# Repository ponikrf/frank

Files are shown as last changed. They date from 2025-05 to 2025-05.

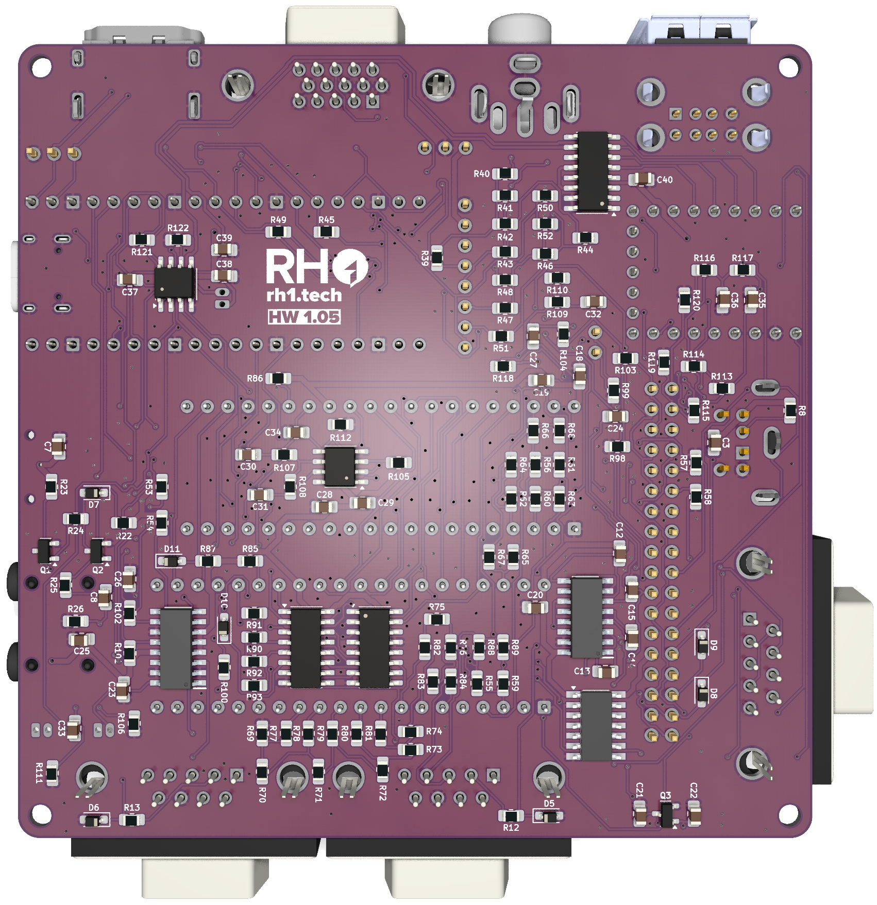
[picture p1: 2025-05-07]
hardware/turbofrank/DOCS/back.png

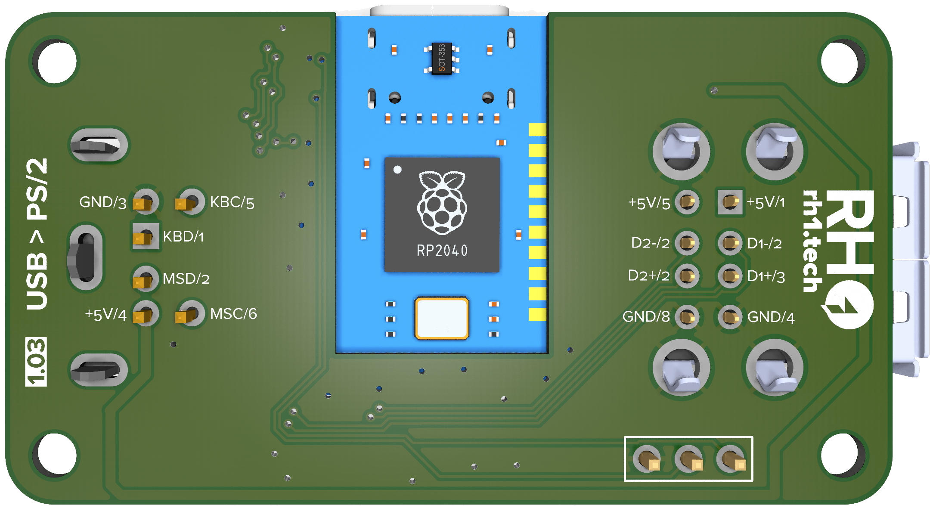
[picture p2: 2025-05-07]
hardware/usb2ps2/DOCS/back.png

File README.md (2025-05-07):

# FRANK

FRANK is a versatile hardware emulation platform based on Raspberry Pico and Raspberry Zero. It is a hardware fork of the [Murmulator](https://murmulator.ru/) project by [Alex Ekb](https://t.me/Alex_Eburg), incorporating numerous additional features.

The name "FRANK" is derived from "Frankenstein" as it integrates various components from different projects, similar to how Dr. Frankenstein created his monster from different parts. This combination enables FRANK to offer a unique and powerful set of capabilities.

## Supported Platforms

FRANK supports emulation for a variety of platforms, including:

* ZX Spectrum (48K, 128K and other models, including clones)
* IBM PC XT 8088
* BK-0011М (soviet 8 bit home computer)
* Radio 86RK (soviet 8 bit home computer)
* Atari 800
* NES/Famicom (also known as Dendy)
* Sega Master System
* Sega Game Gear
* NEC PC Engine / TurboGrafx 16
* Sega MegaDrive / Genesis
* Nintendo GameBoy
* Nintendo GameBoy Color
* Watara Supervision
* Atari Lynx
* Bandai Wonderswan
* NeoGeo Pocket Color
* Picomite MMBasic
* VersaTerm
* DOOM
* Macintosh 512K
* MurmulatorOS

## FRANK Models

Currently there are the following versions of FRANK available:

* [FRANK M1](./hardware/frank_m1) (latest hardware revision: 1.17)
* [FRANK M2](./hardware/frank_m2) (latest hardware revision: 1.03)
* [MiniFRANK RM1](./hardware/minifrank_rm1) (latest hardware revision: 2.07)
* [TurboFRANK](./hardware/turbofrank) (latest hardware revision: 1.07)

## Side Projects

* [HDMI2VGA](./hardware/hdmi2vga) - HDMI to VGA/Soft Composite passive adaptor (latest hardware revision: 2.03)
* [USB2PS2](./hardware/usb2ps2) - USB to PS/2 adapter built on RP2040-Zero (latest hardware revision: 1.03)

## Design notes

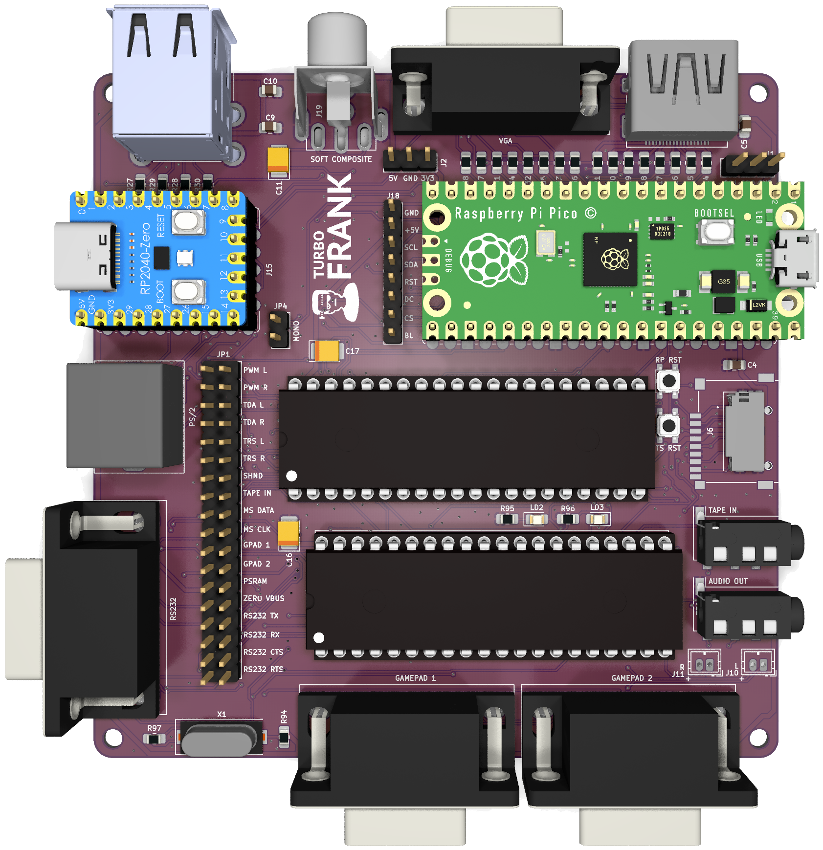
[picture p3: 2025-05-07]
hardware/turbofrank/DOCS/front.png

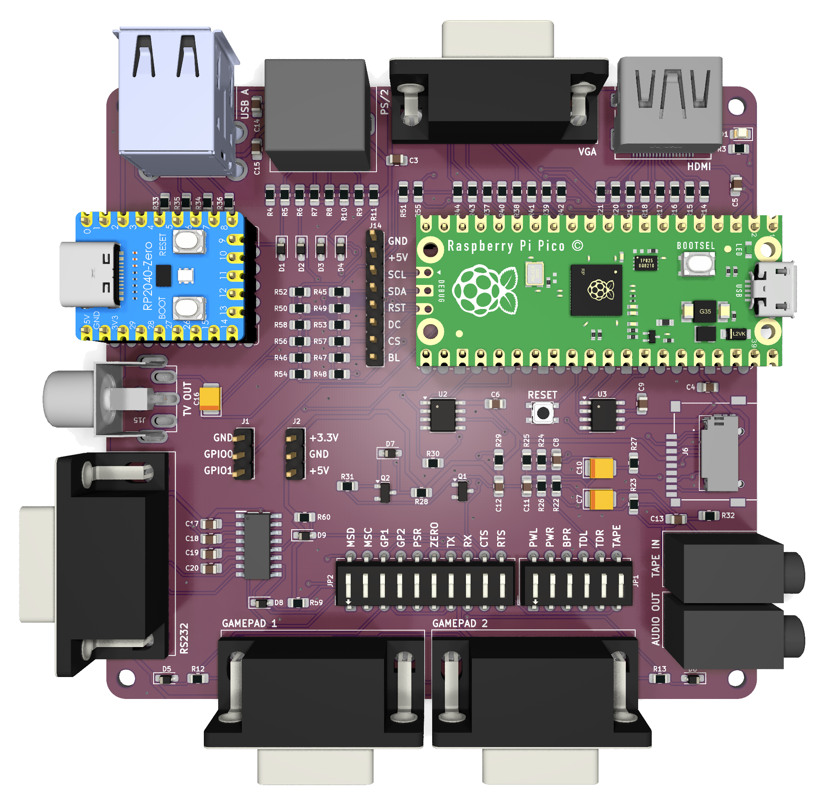
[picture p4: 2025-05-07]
hardware/frank_m1/DOCS/front.png

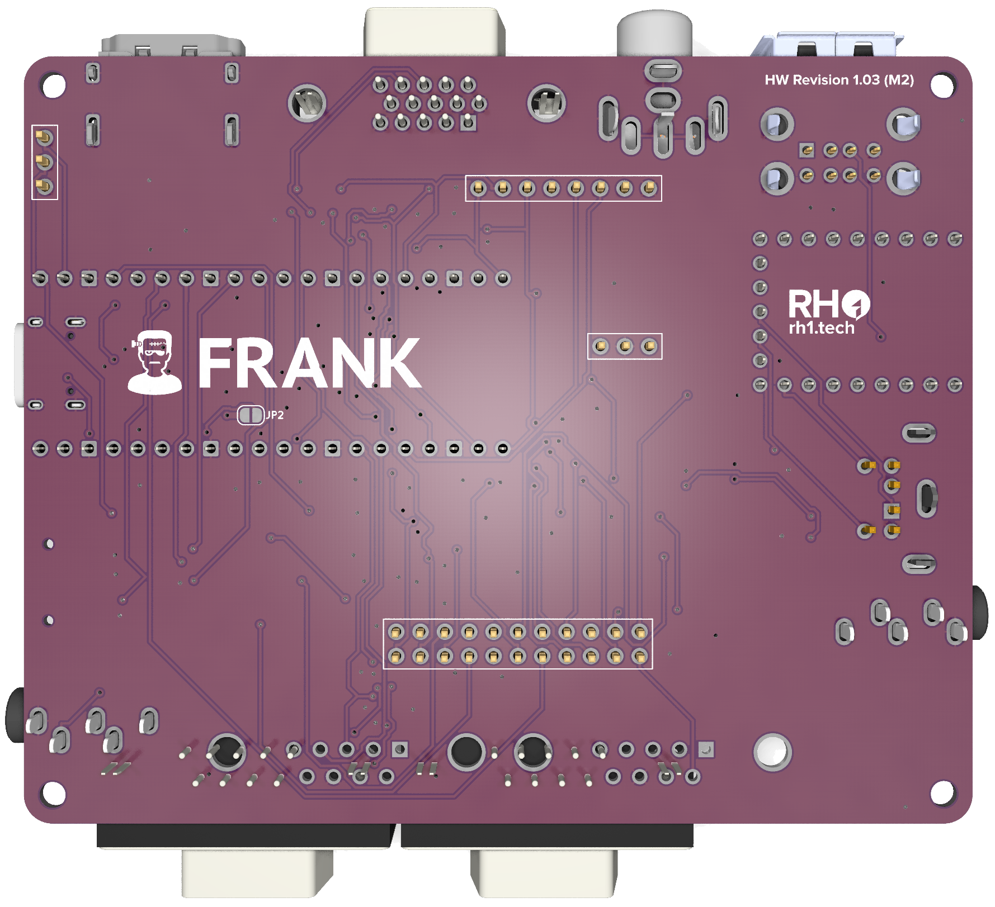
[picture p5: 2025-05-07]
hardware/frank_m2/DOCS/back.png

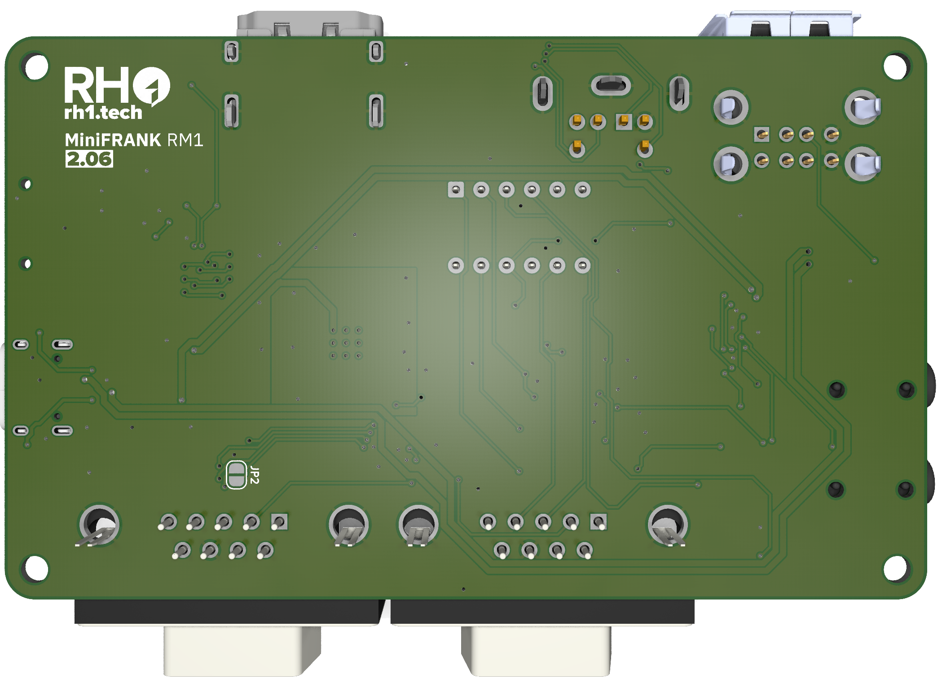
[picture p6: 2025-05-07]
hardware/minifrank_rm1/DOCS/back.png

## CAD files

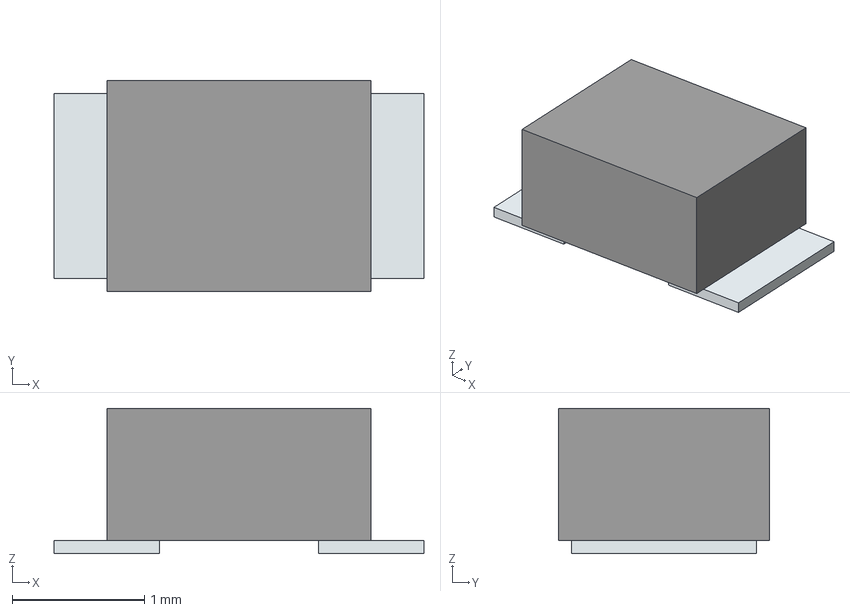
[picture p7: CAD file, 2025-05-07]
lab/minifrank_rm2/3D/ASMPH-0806-3R3M-T.stp
2.80 x 1.60 x 1.10 mm
Pins

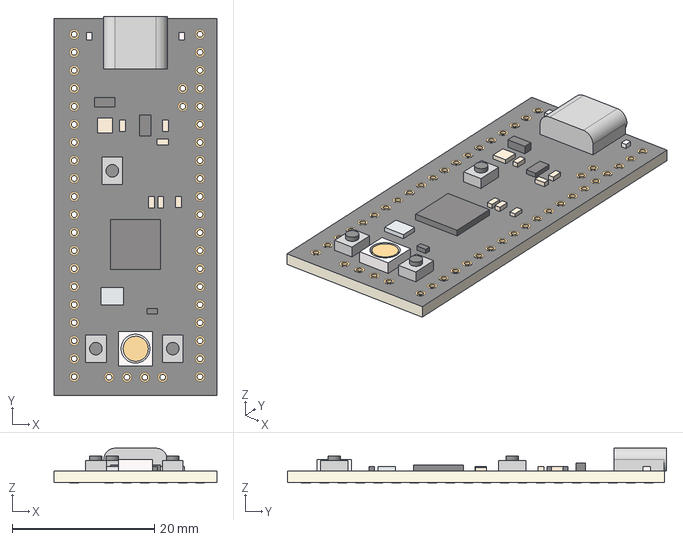
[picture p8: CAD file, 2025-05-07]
hardware/frank_m1/3D/PICO Black.step
22.9 x 53.3 x 4.88 mm

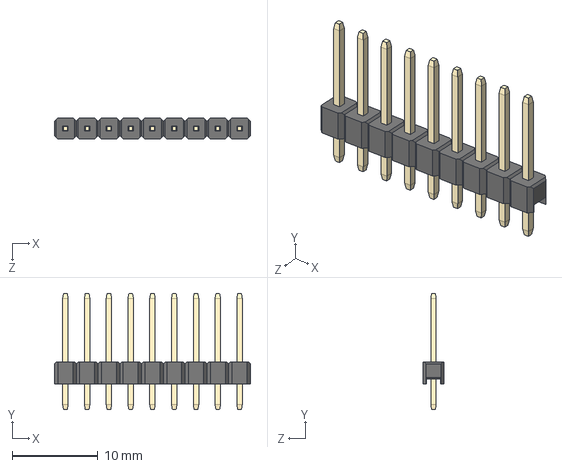
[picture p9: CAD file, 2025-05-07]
hardware/frank_m2/3D/1x9 Male Pin Header.STEP
22.9 x 13.5 x 2.50 mm

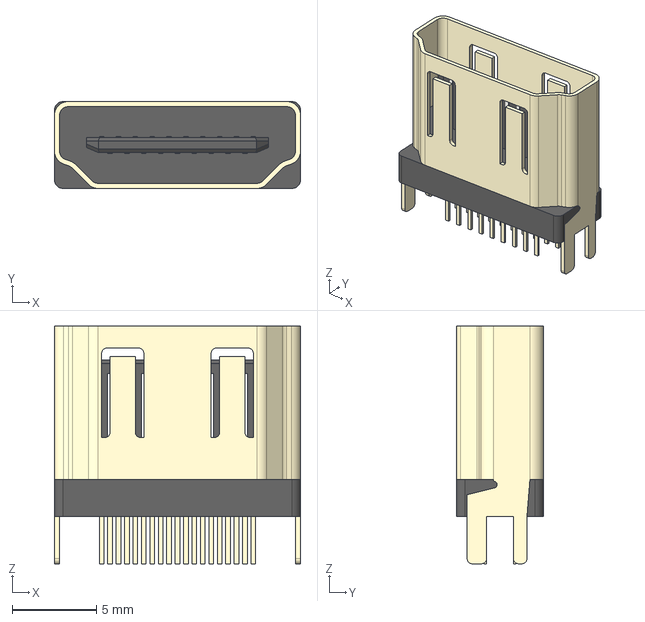
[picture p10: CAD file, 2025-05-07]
hardware/hdmi2vga/3D/HDMI_vertical.stp
14.6 x 5.15 x 14.1 mm

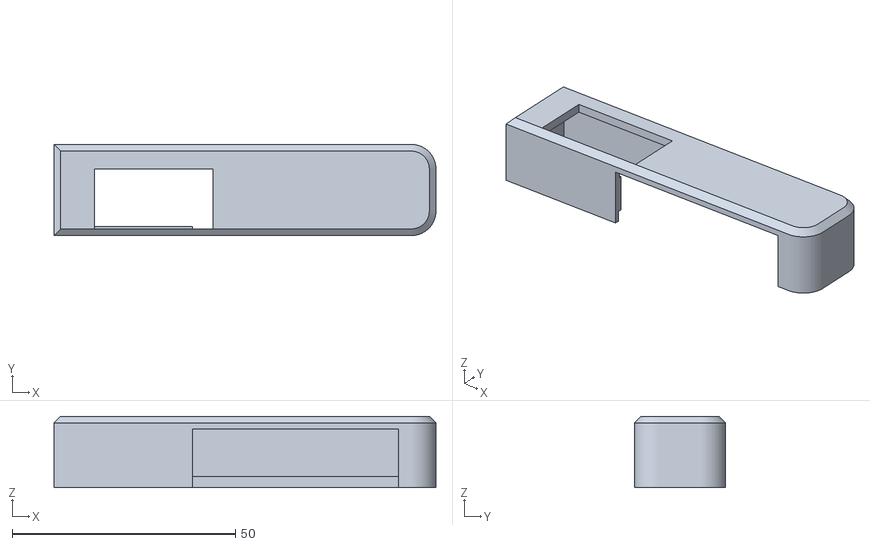
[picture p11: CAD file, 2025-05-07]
hardware/hdmi2vga/CASE/2_02/top.stl
85.5 x 20.4 x 16.0

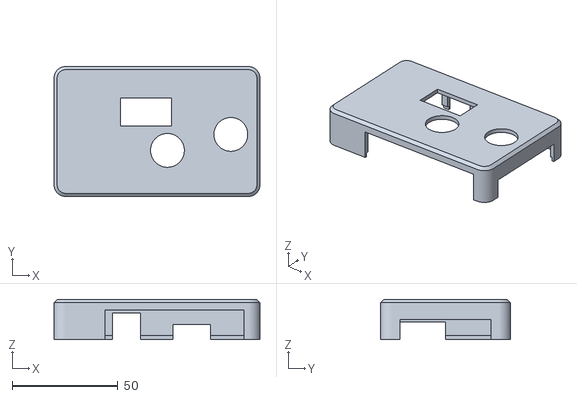
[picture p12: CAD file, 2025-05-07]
hardware/minifrank_rm1/CASE/2_06/top.stl
97.5 x 61.5 x 19.0

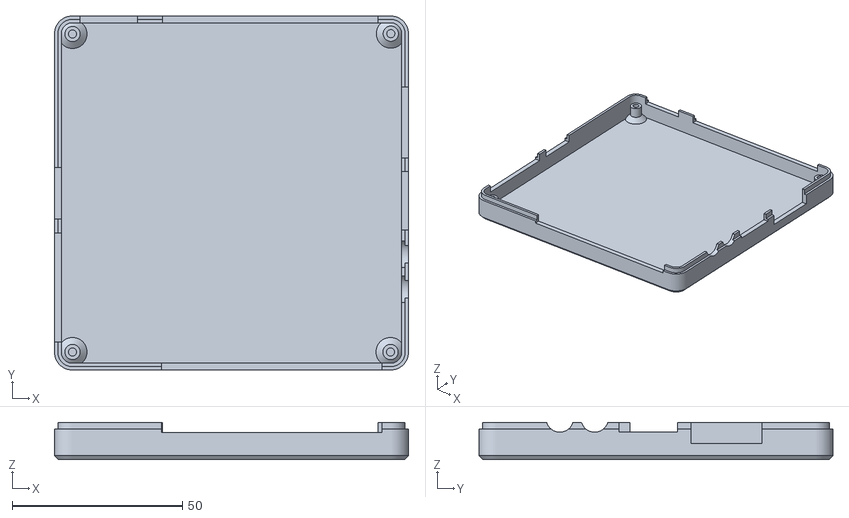
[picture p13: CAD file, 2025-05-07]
hardware/turbofrank/CASE/1_06/bottom.stl
104.0 x 104.0 x 11.0

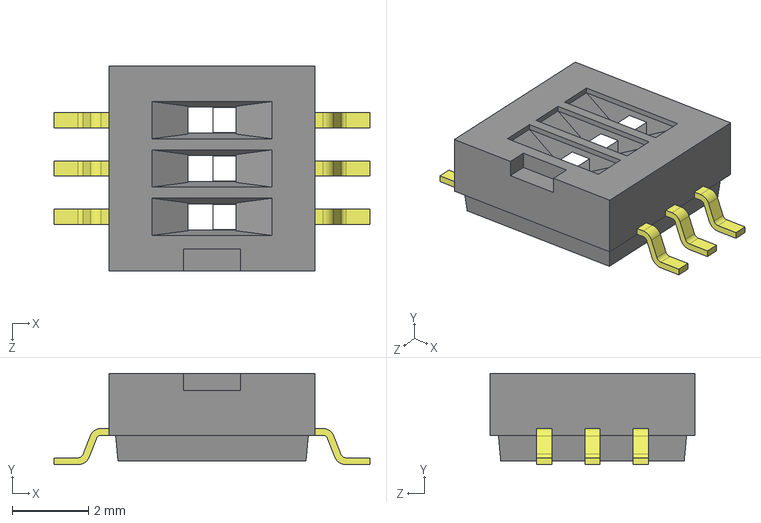
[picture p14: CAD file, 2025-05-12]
lab/minifrank_rm2/3D/DS05-127-2-03BK-SMT-TR.step
8.30 x 2.40 x 5.38 mm

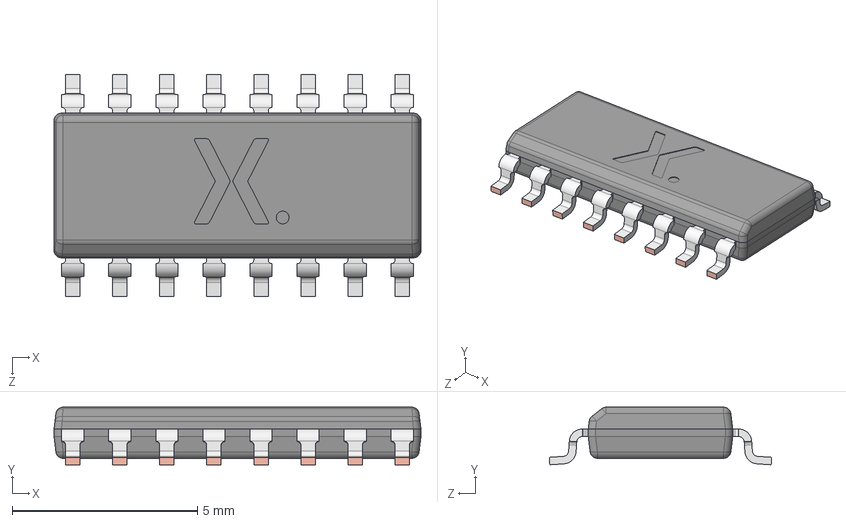
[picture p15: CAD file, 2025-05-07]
lab/nyx2/3D/74HC4052D,653.stp
9.90 x 1.56 x 6.00 mm
SOT109-1 lower body
SOT109-1 upper body
SOT109-1 Lead

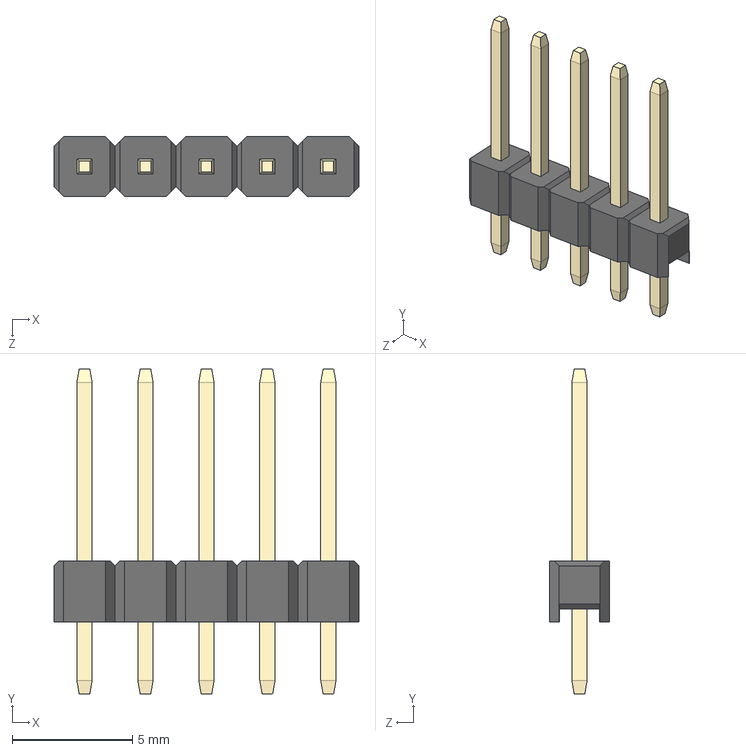
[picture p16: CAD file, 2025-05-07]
hardware/frank_m1/3D/1x5 Male Pin Header.STEP
12.7 x 13.5 x 2.50 mm

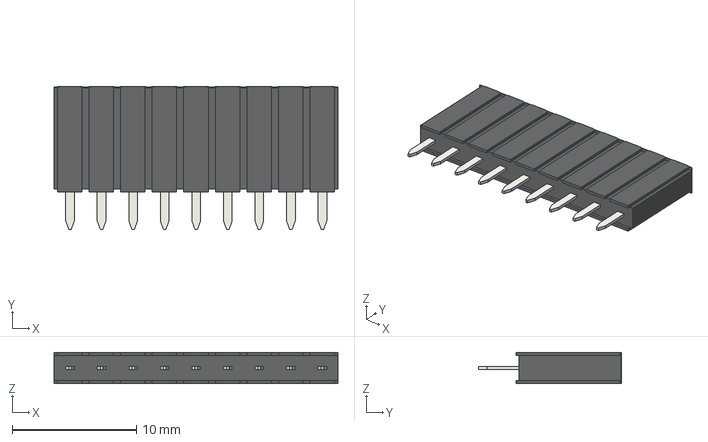
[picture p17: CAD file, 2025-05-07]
hardware/frank_m2/3D/FHU-1x9.step
22.9 x 11.5 x 2.50 mm

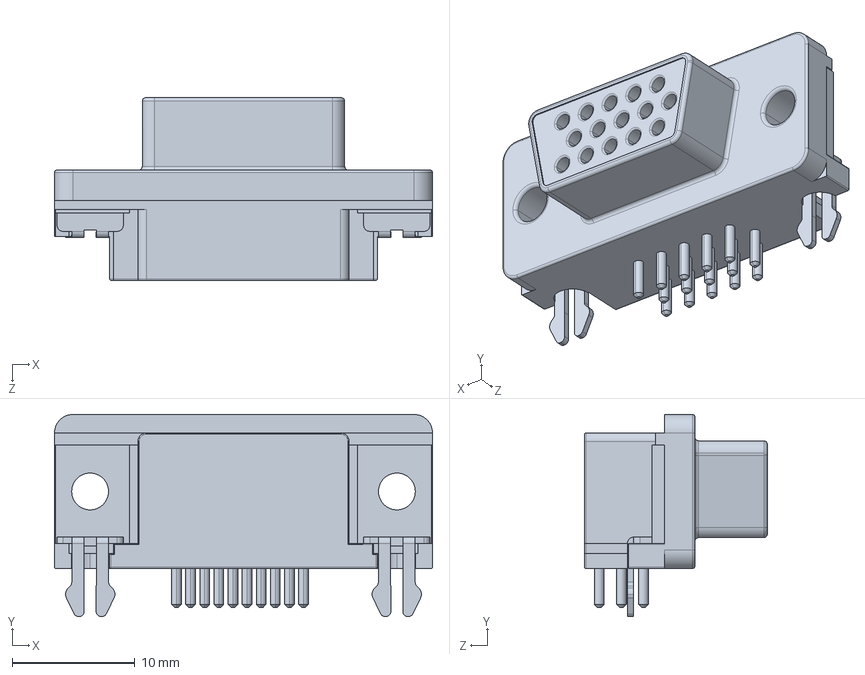
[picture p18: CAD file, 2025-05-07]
hardware/hdmi2vga/3D/VGA connector on plate (short).STEP
30.8 x 16.5 x 14.9 mm

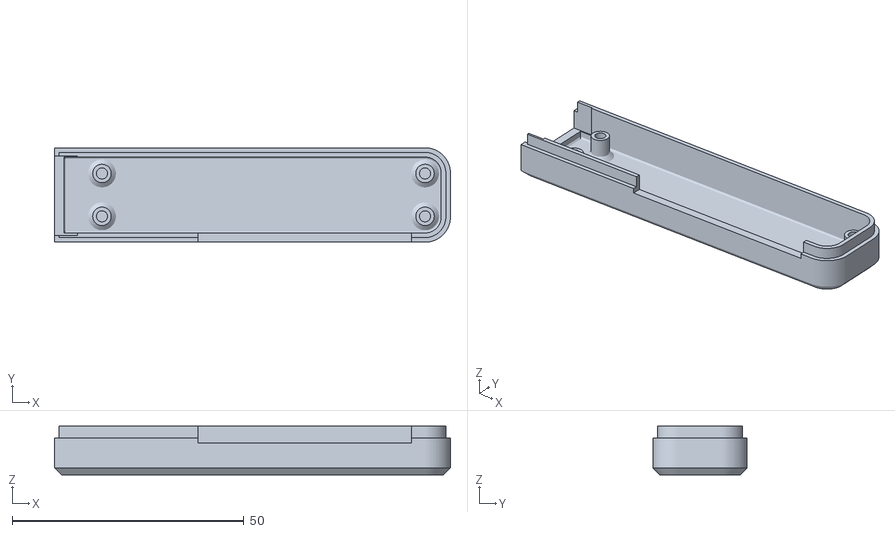
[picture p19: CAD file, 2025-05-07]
hardware/hdmi2vga/CASE/2_02/bottom.stl
85.5 x 20.4 x 10.5

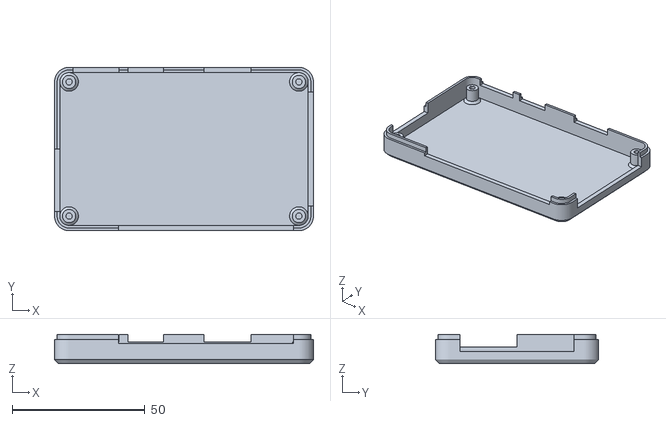
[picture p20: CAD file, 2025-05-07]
hardware/minifrank_rm1/CASE/2_06/bottom.stl
97.5 x 61.5 x 11.0

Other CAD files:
hardware/turbofrank/CASE/1_06/top.stl
lab/minifrank_rm2/3D/TS3USB221RSER.stp
hardware/frank_m1/3D/1x20 Male Pin Header.STEP
hardware/frank_m1/3D/FHU-1x20.step
hardware/frank_m1/3D/FHU-1x5.step
hardware/frank_m2/3D/1x20 Male Pin Header.STEP
hardware/frank_m2/3D/FHU-1x20.step
hardware/frank_m2/3D/FHU-1x5.step
hardware/turbofrank/3D/1x20 Male Pin Header.STEP
hardware/turbofrank/3D/FHU-1x20.step
hardware/turbofrank/3D/FHU-1x5.step
hardware/turbofrank/3D/Micro_SD_Card_and_Holder.stp
lab/minifrank_rm2/3D/3225 SMD Crystal Oscillator.STEP
lab/minifrank_rm2/3D/47571-0001.stp
lab/minifrank_rm2/3D/CUI_DEVICES_RCJ-013.step
lab/minifrank_rm2/3D/DS05-127-2-04BK-SMT-TR.step
lab/minifrank_rm2/3D/DSUB-15-HD_Male_Horizontal_P2.29x1.98mm_EdgePinOffset3.03mm_Housed_MountingHolesOffset4.94mm.step
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

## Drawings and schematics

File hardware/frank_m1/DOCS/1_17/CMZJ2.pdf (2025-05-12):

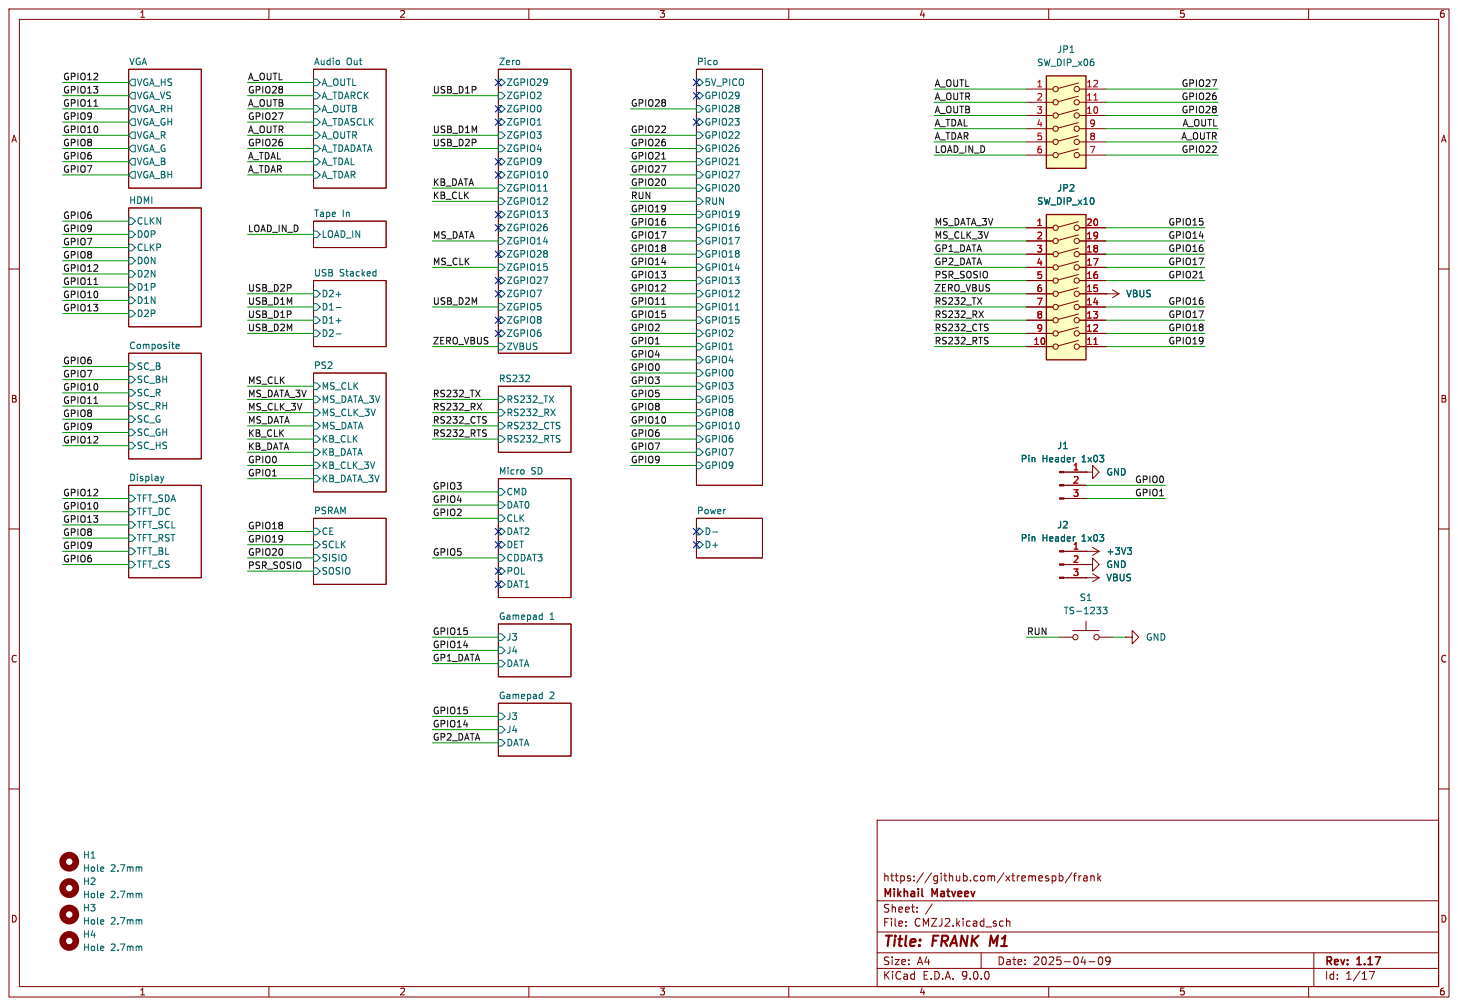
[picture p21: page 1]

J1 Pin Header 1x03 GND GND 123

DAT0 CLK DAT2 DET CDDAT3 POL DAT1 Micro SD

https://github.com/xtremespb/frank

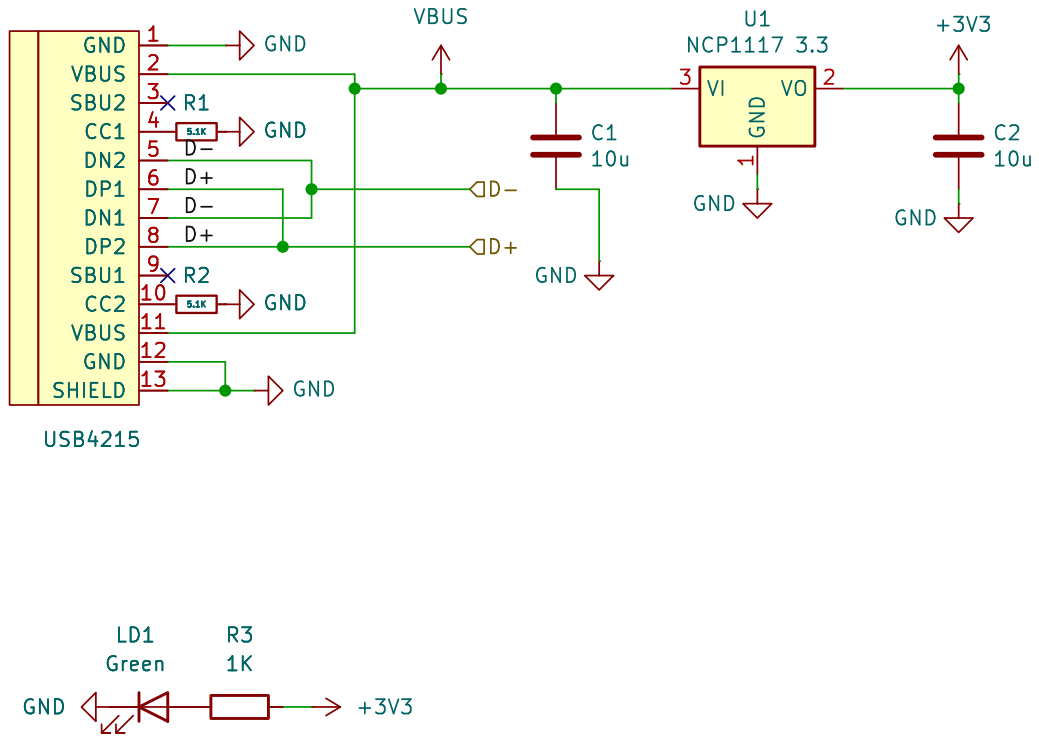
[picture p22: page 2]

https://github.com/xtremespb/frank R2

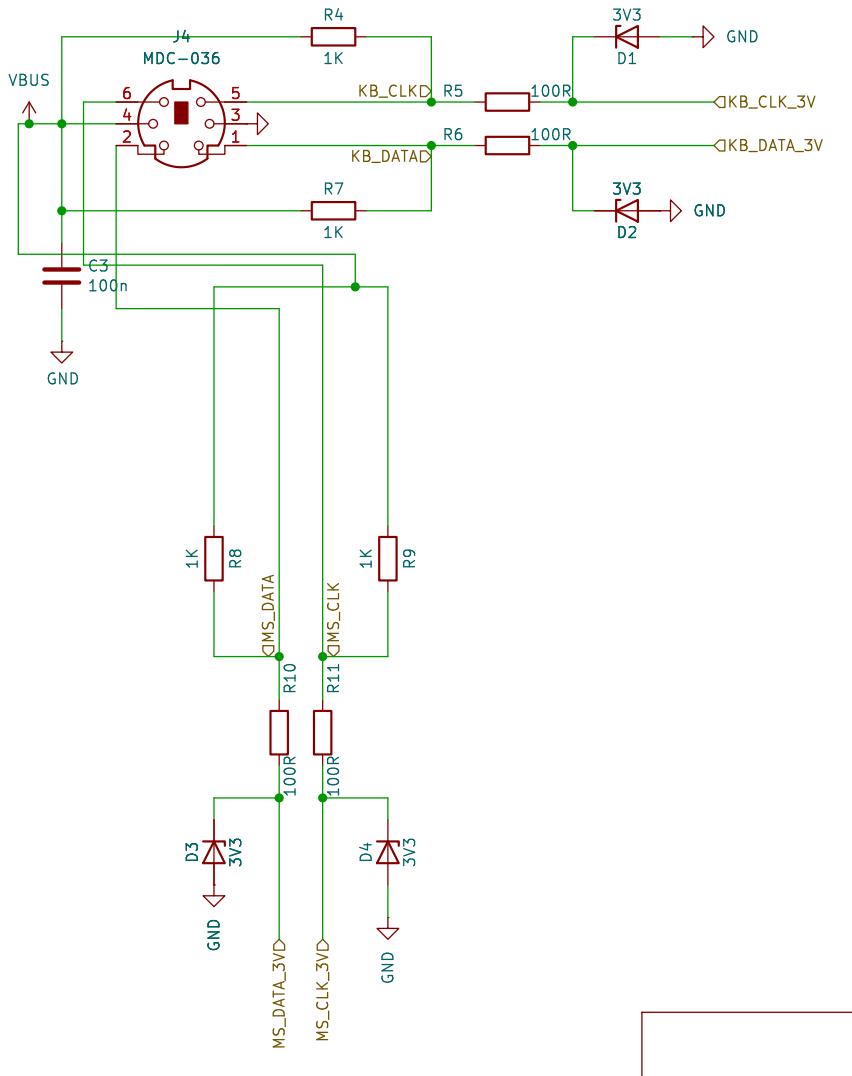
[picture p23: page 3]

https://github.com/xtremespb/frank

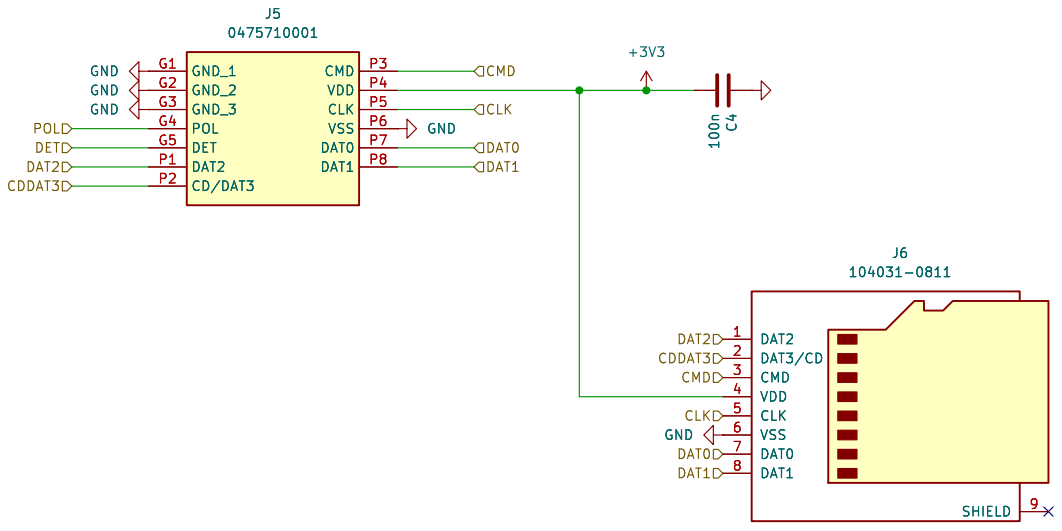
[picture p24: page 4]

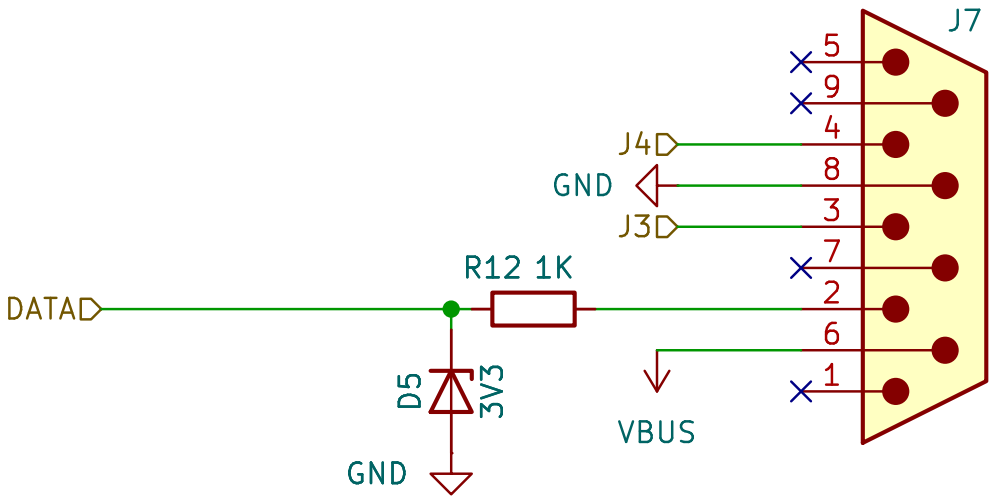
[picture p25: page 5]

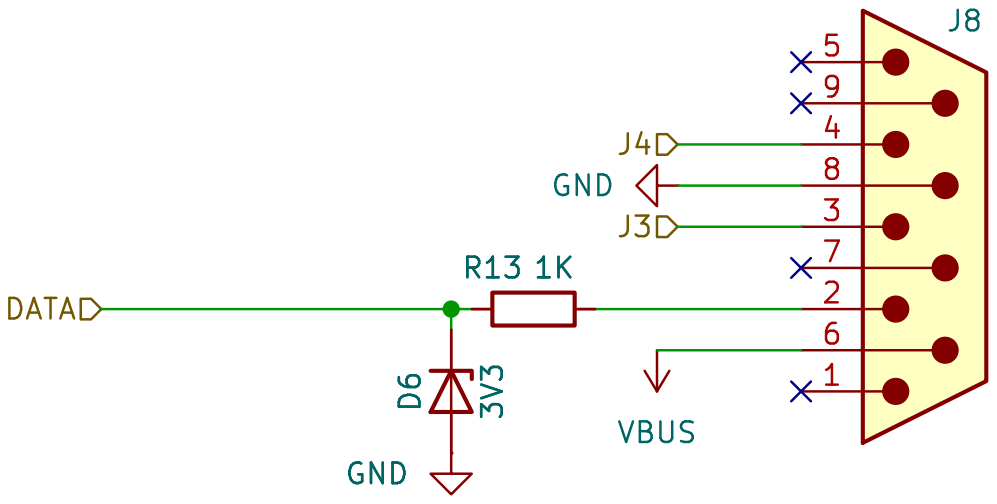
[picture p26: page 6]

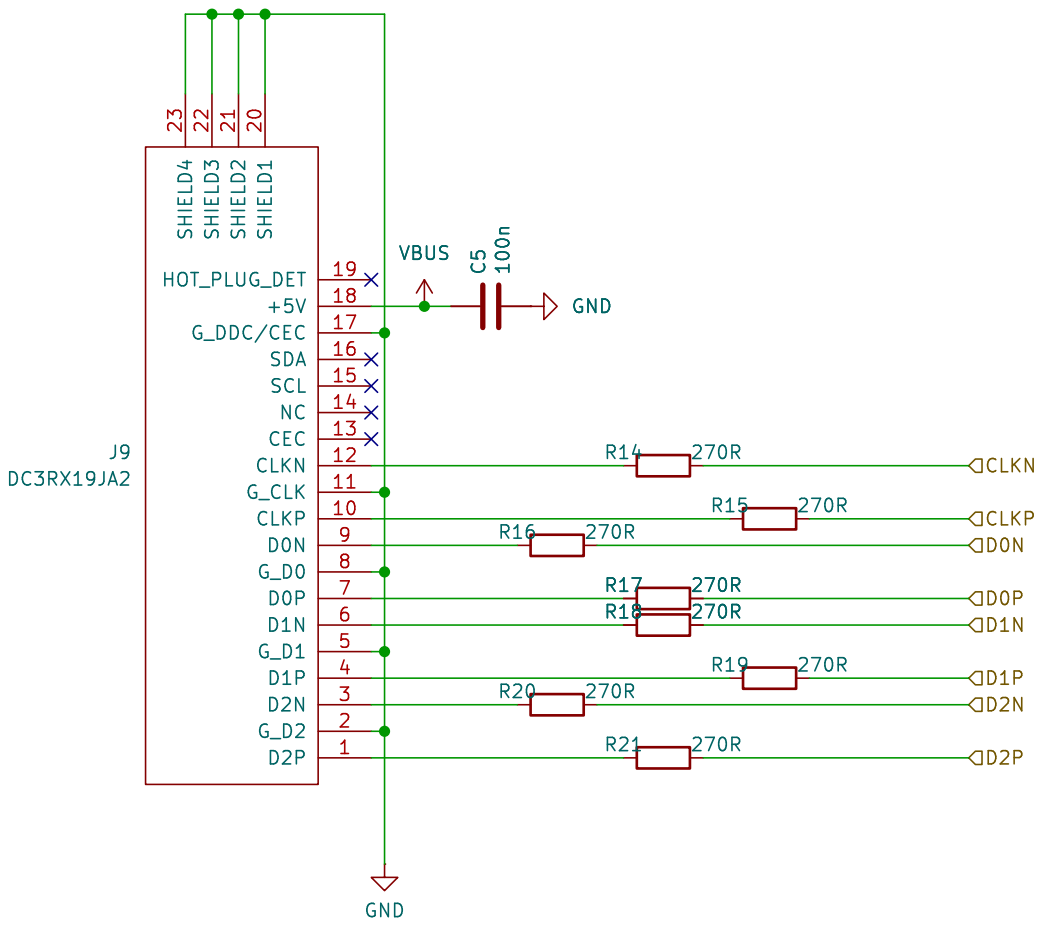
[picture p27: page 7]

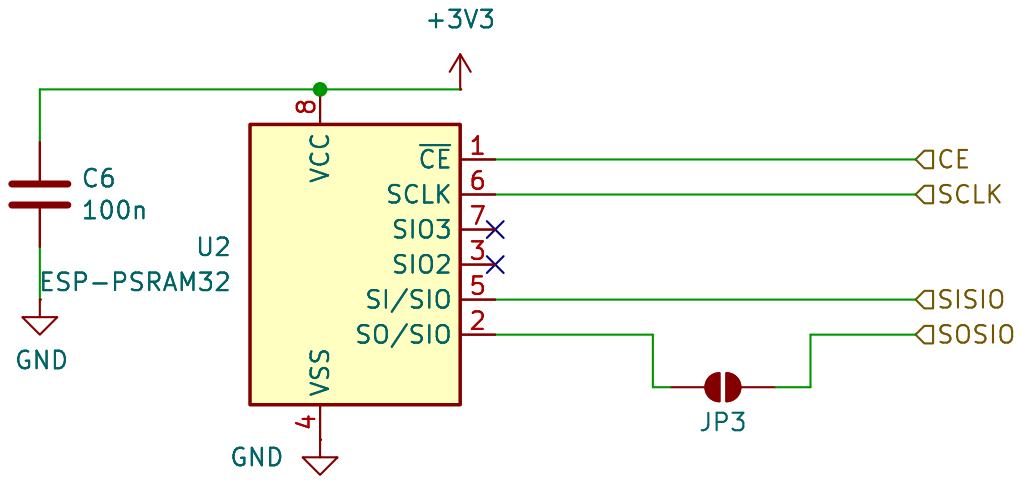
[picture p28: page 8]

4 ~{CE}1 SCLK 6 SIO3 7 SIO2 3 SI/SIO 5 SO/SIO 2 +3V3

4 ~{CE}1 SCLK 6 SIO3 7 SIO2 3 SI/SIO 5 SO/SIO 2 U2 ESP-PSRAM32 GND

https://github.com/xtremespb/frank C6

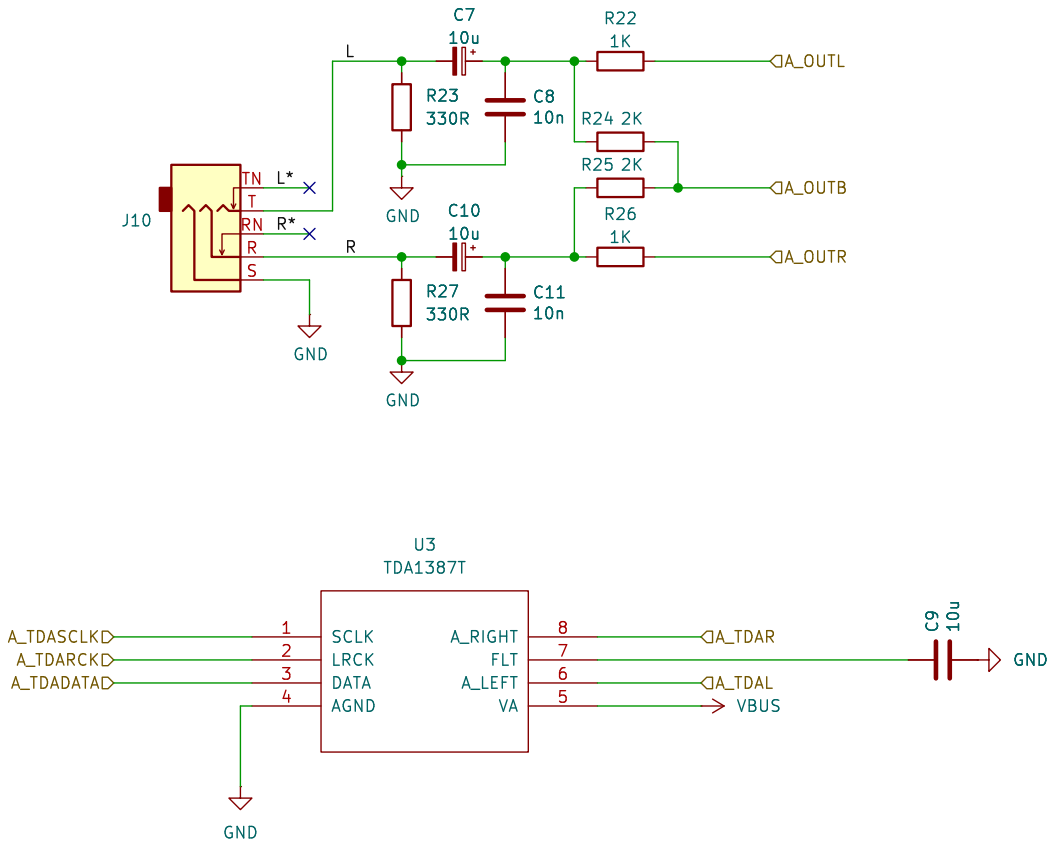
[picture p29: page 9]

https://github.com/xtremespb/frank

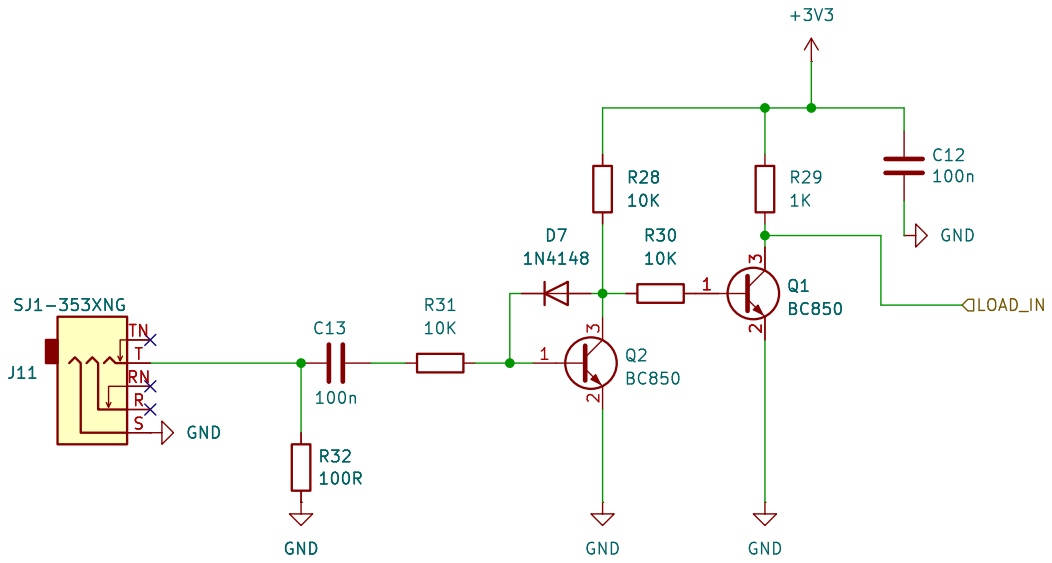
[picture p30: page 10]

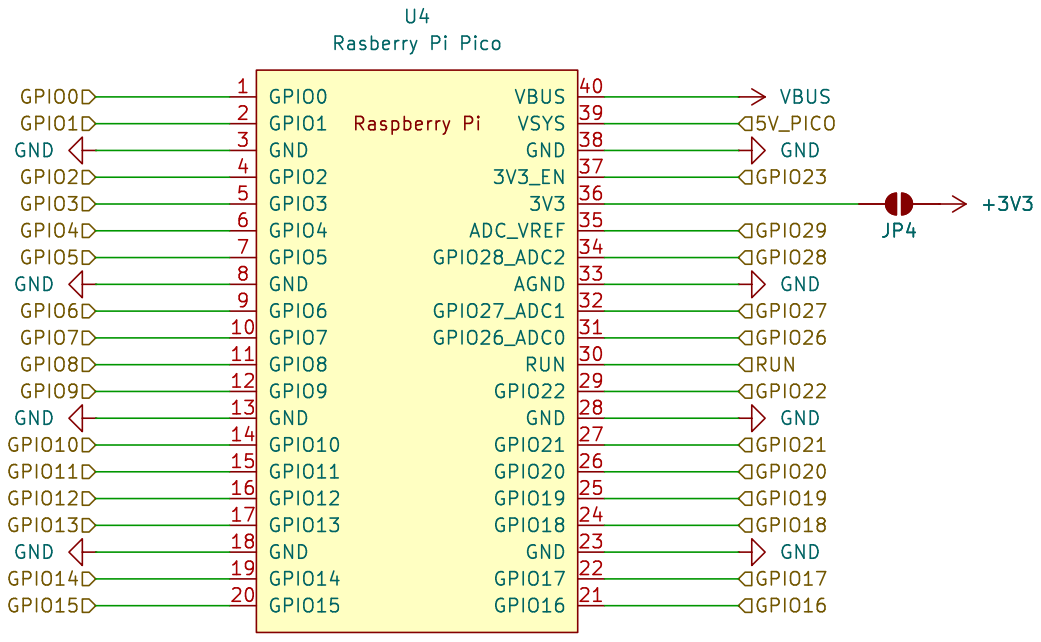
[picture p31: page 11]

https://github.com/xtremespb/frank GND

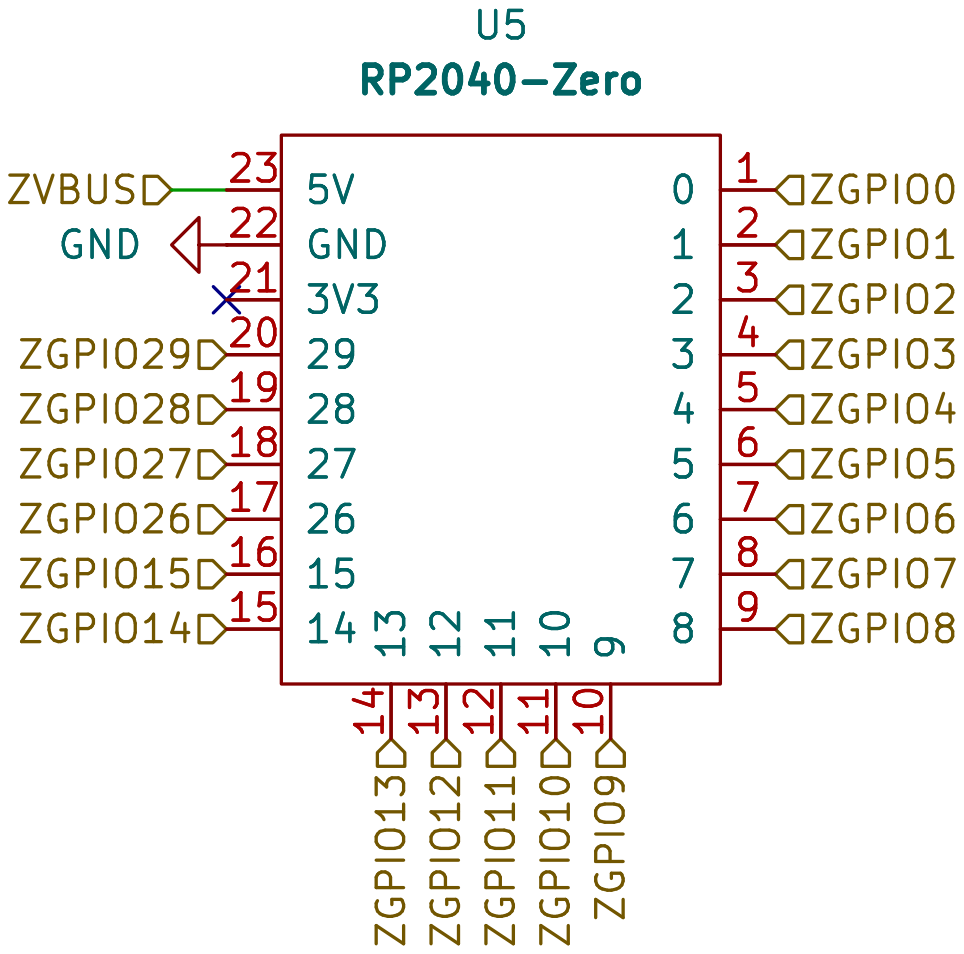
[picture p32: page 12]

https://github.com/xtremespb/frank GND



https://github.com/xtremespb/frank


https://github.com/xtremespb/frank


https://github.com/xtremespb/frank


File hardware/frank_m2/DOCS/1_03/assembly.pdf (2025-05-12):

# D3 R46 J15


https://github.com/xtremespb/frank Black And White TOP - Page 1/4

File: HR3FQ.kicad_pcb Sheet: Black And White TOP Mikhail Matveev

D Date: 2025-03-16 KiCad; E.D.A. 9.0.0 Size: A4; Rev: 1.03; File: HR3FQ.kicad_pcb Sheet: Black; And; White; BOT Mikhail; Matveev; https://github.com/xtremespb/frank Black; BOT -; Page 2/4

Id: /1 Title: FRANK M2

# D3 R46 J15


D Date: 2025-03-16 KiCad; E.D.A. 9.0.0 Size: A4; Rev: 1.03; File: HR3FQ.kicad_pcb Sheet: Colored; BOT Mikhail; Matveev; https://github.com/xtremespb/frank Colored; BOT -; Page 4/4; Jumper (Solder)

Id: /1 Title: FRANK M2

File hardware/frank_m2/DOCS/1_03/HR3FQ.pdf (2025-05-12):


ZERO_VBUS
DAT0 CLK DAT2 DET CDDAT3 POL DAT1 Micro SD

https://github.com/xtremespb/frank


1 VO 2 U1 GND NCP1117 3.3 1 VBUS 2 SBU2 3 CC1 4 DN2 5 DP1 6 DN1 7 DP2 8 SBU1 9 CC2 10 VBUS 11 GND 12 SHIELD 13 USB4215 GND

https://github.com/xtremespb/frank


https://github.com/xtremespb/frank GND



https://github.com/xtremespb/frank


https://github.com/xtremespb/frank



https://github.com/xtremespb/frank


https://github.com/xtremespb/frank SR
100R GND


https://github.com/xtremespb/frank


https://github.com/xtremespb/frank



https://github.com/xtremespb/frank



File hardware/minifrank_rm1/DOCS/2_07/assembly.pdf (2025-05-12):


MM USB AUDIO RESET BOOT AUDIO OUT TAPE IN R1 U1 C8 R49 R46 R8 R11 R57 U2 C33 C11 C39 C34 D3 R50 R27D4 C20 C31

https://github.com/xtremespb/frank Black And White TOP - Page 1/4

File: minifrank_rm1.kicad_pcb Sheet: Black And White TOP Mikhail Matveev

D Date: 2025-04-24 KiCad; E.D.A. 9.0.0 Size: A4; Rev: 2.07; File: minifrank_rm1.kicad_pcb Sheet: Black; And; White; BOT Mikhail; Matveev; https://github.com/xtremespb/frank Black; BOT -; Page 2/4

Id: /1 Title: MiniFRANK RM1


D Date: 2025-04-24 KiCad; E.D.A. 9.0.0 Size: A4; Rev: 2.07; File: minifrank_rm1.kicad_pcb Sheet: Colored; BOT Mikhail; Matveev; https://github.com/xtremespb/frank Colored; BOT -; Page 4/4 Jumper (Solder)

Id: /1 Title: MiniFRANK RM1

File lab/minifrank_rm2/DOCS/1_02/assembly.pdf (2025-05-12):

J8 | R6U1 R10 | R47 R³¹ | JP¹ R11 | C⁴⁰ R⁴⁰ R8 C13 | R7 1 | 2 | 3 | 4 | 5 | 6 1 | 2 | 3 | 4 | 5 | 6 ABCD | ABCD Date: 2025-05-11 KiCad E.D.A. 9.0.0 Size: A4 | Rev: 1.02


BOOT USB TAPE IN GAMEPAD 1 TAPE IN AUDIO OUT AUDIO

https://github.com/xtremespb/frank Black And White TOP - Page 1/4

File: minifrank_rm2.kicad_pcb Sheet: Black And White TOP Mikhail Matveev

1 | 2 | 3 | 4 | 5 | 6

A

D Date: 2025-05-11 KiCad; E.D.A. 9.0.0 Size: A4; Rev: 1.02; File: minifrank_rm2.kicad_pcb Sheet: Black; And; White; BOT Mikhail; Matveev; https://github.com/xtremespb/frank Black; BOT -; Page 2/4

Id: /1 Title: MiniFRANK RM2

1 | 2 | 3 | 4 | 5 | 6 1 | 2 | 3 | 4 | 5 | 6 ABCD | ABCD Date: 2025-05-11 KiCad | E.D.A. 9.0.0 Size: A4 | Rev: 1.02
https://github.com/xtremespb/frank Colored | TOP - | Page 3/4 | BOOT USB TAPE IN GAMEPAD ¹ | TAPE IN AUDIO OUT | AUDIO


1 | 2 | 3 | 4 | 5 | 6

A

D Date: 2025-05-11 KiCad; E.D.A. 9.0.0 Size: A4; Rev: 1.02; File: minifrank_rm2.kicad_pcb Sheet: Colored; BOT Mikhail; Matveev; https://github.com/xtremespb/frank Colored; BOT -; Page 4/4

Id: /1 Title: MiniFRANK RM2

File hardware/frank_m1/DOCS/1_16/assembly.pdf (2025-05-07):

J1 | R49 | R⁵¹ | C⁸ R52 U⁶ | R⁴² | R¹⁹ 1 | 2 | 3 | 4 | 5 | 6 1 | 2 | 3 | 4 | 5 | 6 ABCD | ABCD Date: 2025-03-26 KiCad E.D.A. 9.0.0 Size: A4 | Rev: 1.16

R3 100R


https://github.com/xtremespb/frank Black And White TOP - Page 1/4

File: CMZJ2.kicad_pcb Sheet: Black And White TOP Mikhail Matveev

1 | 2 | 3 | 4 | 5 | 6

A

D Date: 2025-03-26 KiCad; E.D.A. 9.0.0 Size: A4; Rev: 1.16; File: CMZJ2.kicad_pcb Sheet: Black; And; White; BOT Mikhail; Matveev; https://github.com/xtremespb/frank Black; BOT -; Page 2/4; Jumper; (Solder)

Id: /1 Title: FRANK M1

1 | 2 | 3 | 4 | 5 | 6

A

D Date: 2025-03-26 KiCad; E.D.A. 9.0.0 Size: A4; Rev: 1.16; File: CMZJ2.kicad_pcb Sheet: Colored; BOT Mikhail; Matveev; https://github.com/xtremespb/frank Colored; BOT -; Page 3/4; Jumper; (Solder)

Id: /1 Title: FRANK M1

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

R3 100R


https://github.com/xtremespb/frank Colored TOP - Page 4/4

File: CMZJ2.kicad_pcb Sheet: Colored TOP Mikhail Matveev

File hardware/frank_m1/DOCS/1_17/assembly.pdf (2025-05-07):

# VGA RTS TDR


https://github.com/xtremespb/frank Black And White TOP - Page 1/4

File: CMZJ2.kicad_pcb Sheet: Black And White TOP Mikhail Matveev

D Date: 2025-04-09 KiCad; E.D.A. 9.0.0 Size: A4; Rev: 1.17; File: CMZJ2.kicad_pcb Sheet: Black; And; White; BOT Mikhail; Matveev; https://github.com/xtremespb/frank Black; BOT -; Page 2/4

Id: /1 Title: FRANK M1

# VGA RTS TDR


D Date: 2025-04-09 KiCad; E.D.A. 9.0.0 Size: A4; Rev: 1.17; File: CMZJ2.kicad_pcb Sheet: Colored; BOT Mikhail; Matveev; https://github.com/xtremespb/frank Colored; BOT -; Page 4/4; Jumper; (Solder)

Id: /1 Title: FRANK M1

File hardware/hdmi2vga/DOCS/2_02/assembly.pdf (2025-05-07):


D Date: 2025-03-04 KiCad; E.D.A. 9.0.0 Size: A4; Rev: 2.01; Id: /1 Title: HDMI to VGA Passive Adapter File: hdmi2vgaP.kicad_pcb Sheet: Black; And; White; BOT Mikhail; Matveev; https://github.com/xtremespb/frank Black; BOT -; Page 2/2

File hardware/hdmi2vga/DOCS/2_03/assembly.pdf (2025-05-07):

D Date: 2025-05-07 KiCad; E.D.A. 9.0.0 Size: A4; Rev: 2.03; Id: /1 Title: HDMI2VGA; File: hdmi2vga.kicad_pcb Sheet: Black; And; White; TOP Mikhail; Matveev; https://github.com/xtremespb/frank Black; TOP -; Page

D Date: 2025-05-07 KiCad; E.D.A. 9.0.0 Size: A4; Rev: 2.03; Id: /1 Title: HDMI2VGA; File: hdmi2vga.kicad_pcb Sheet: Black; And; White; BOT Mikhail; Matveev; https://github.com/xtremespb/frank Black; BOT -; Page 2/4

D Date: 2025-05-07 KiCad; E.D.A. 9.0.0 Size: A4; Rev: 2.03; Id: /1 Title: HDMI2VGA; File: hdmi2vga.kicad_pcb Sheet: Colored; TOP Mikhail; Matveev; https://github.com/xtremespb/frank Colored; TOP -; Page 3/4 L1

D Date: 2025-05-07 KiCad; E.D.A. 9.0.0 Size: A4; Rev: 2.03; Id: /1 Title: HDMI2VGA; File: hdmi2vga.kicad_pcb Sheet: Colored; BOT Mikhail; Matveev; https://github.com/xtremespb/frank Colored; BOT -; Page 4/4

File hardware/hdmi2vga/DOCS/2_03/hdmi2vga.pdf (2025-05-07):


https://github.com/xtremespb/frank GND

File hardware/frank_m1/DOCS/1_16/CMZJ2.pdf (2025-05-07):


DAT0 CLK DAT2 DET CDDAT3 POL DAT1 Micro SD


https://github.com/xtremespb/frank



https://github.com/xtremespb/frank


https://github.com/xtremespb/frank


https://github.com/xtremespb/frank


https://github.com/xtremespb/frank


4 ~{CE}1 SCLK 6 SIO3 7 SIO2 3 SI/SIO 5 SO/SIO 2 U2 ESP-PSRAM32 C6

4 ~{CE}1 SCLK 6 SIO3 7 SIO2 3 SI/SIO 5 SO/SIO 2 C6

https://github.com/xtremespb/frank


https://github.com/xtremespb/frank


https://github.com/xtremespb/frank


https://github.com/xtremespb/frank


https://github.com/xtremespb/frank


https://github.com/xtremespb/frank


https://github.com/xtremespb/frank


https://github.com/xtremespb/frank


https://github.com/xtremespb/frank


J16 D-SUB 9 Male GND GND

https://github.com/xtremespb/frank

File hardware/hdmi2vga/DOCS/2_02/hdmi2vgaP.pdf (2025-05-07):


https://github.com/xtremespb/frank


https://github.com/xtremespb/frank


https://github.com/xtremespb/frank


https://github.com/xtremespb/frank

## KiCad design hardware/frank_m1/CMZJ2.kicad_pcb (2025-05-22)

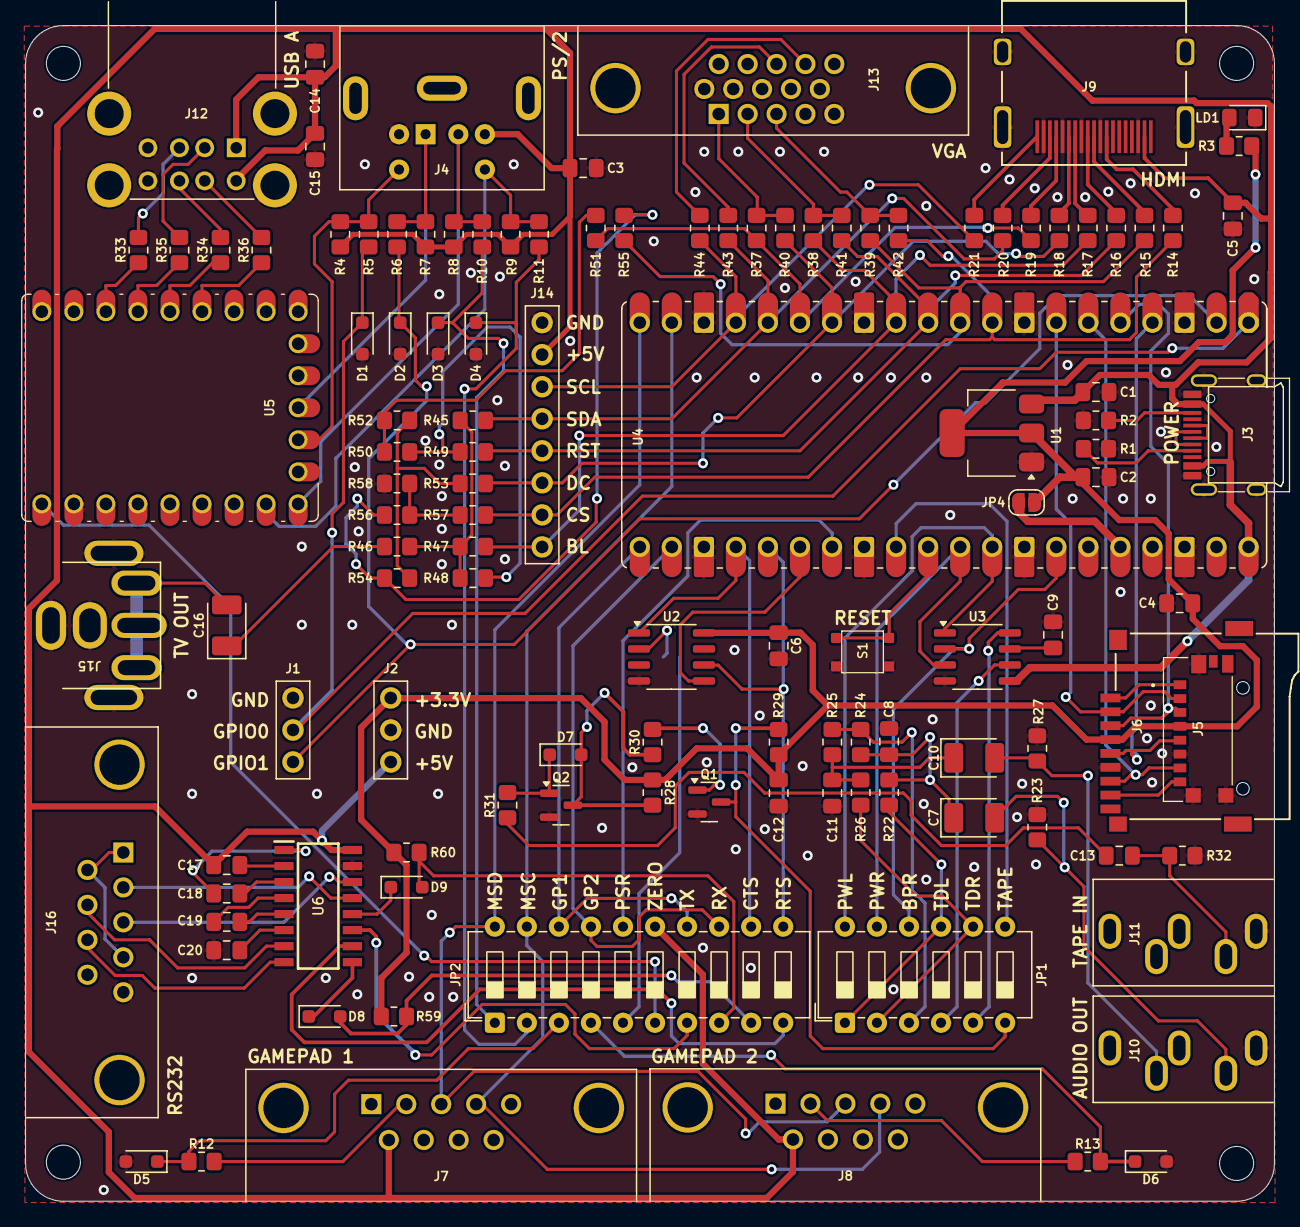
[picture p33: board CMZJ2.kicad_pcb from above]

Board: 2 copper layers, 99.0 x 93.2 mm, 123 parts (1 on the bottom side), 113 nets.

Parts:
C1, C2, C9, C14, C15: 10u; Capacitor (0805)
C3, C4, C5, C6, C12, C13: 100n; Capacitor (0805)
C7, C10: 10u; Capacitor (3528, tantalum, polar)
C8, C11: 10n; Capacitor (0805)
C16: 220u; Capacitor (3528, tantalum, polar)
C17, C18, C19, C20: 1u; Capacitor (0805)
D1, D2, D3, D4, D5, D6: 3V3; Diode (SOD-323)
D7, D8, D9: 1N4148; Diode (SOD-323)
H1, H2, H3, H4: Hole 2.7mm; Mounting Hole (2.7mm)
J1, J2: Pin Header 1x03; Pin Header (1x03)
J3: USB4215; USB Type C
J4: MDC-036; MiniDIN (6 Pin, female)
J5: 0475710001; MicroSD (SMD, short)
J6: 104031-0811; MicroSD (SMD, long)
J7, J8, J16: D-SUB 9 Male; D-SUB (9 pin, male, top mount)
J9: DC3RX19JA2; HDMI (female)
J10, J11: SJ1-353XNG; Jack (3.5mm)
J12: SS-52100-004; USB Type A (stacked)
J13: D-SUB 15 Female; D-SUB (15 pin, female)
J14: Pin Header 1x08; Pin Header (1x08)
J15: RCA-103; RCA
JP1: SW_DIP_x06; DIP Switch (6)
JP2: SW_DIP_x10; DIP Switch (10)
JP3, JP4: Jumper (Solder); Jumper (solder)
LD1: Green; LED (0805)
Q1, Q2: BC850; SOT-23
R1, R2: 5.1K; Resistor (0805)
R3, R4, R7, R8, R9, R12, R13, R22, R26, R29, R40, R41, R42, R59, R60: 1K; Resistor (0805)
R5, R6, R10, R11, R32, R43, R44: 100R; Resistor (0805)
R14, R15, R16, R17, R18, R19, R20, R21, R47, R49, R51, R53, R55, R57: 270R; Resistor (0805)
R23, R27, R37, R38, R39: 330R; Resistor (0805)
R24, R25: 2K; Resistor (0805)
R28, R30, R31: 10K; Resistor (0805)
R33, R34, R35, R36: 22R; Resistor (0805)
R45: 750R; Resistor (0805)
R46: 51R; Resistor (0805)
R48, R50, R52, R54, R56: 150R; Resistor (0805)
R58: 300R; Resistor (0805)
S1: TS-1233; Button (SMD, 3x3mm, 1-1)
U1: NCP1117 3.3; SOT-223
U2: ESP-PSRAM32; SO-8
U3: TDA1387T; SO-8
U4: Rasberry Pi Pico; Raspberry Pi Pico
U5: RP2040-Zero; Raspberry Pi Zero
U6: MAX232CSE+; SOIC127P600X175-16N

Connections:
+3V3: C2.1, C4.2, C6.1, C12.1, J2.1, J5.P4 (VDD), J6.4 (VDD), JP4.2 (B), R3.2, R28.1, R29.1, R59.2, R60.2, U1.2 (VO), U2.8 (VCC)
/A_OUTB: JP1.3, R24.2, R25.2
/A_OUTL: JP1.1, JP1.9, R22.2
/A_OUTR: JP1.2, JP1.8, R26.2
/A_TDAL: JP1.4, U3.6 (A_LEFT)
/A_TDAR: JP1.5, U3.8 (A_RIGHT)
/Audio Out/L: C7.2, J10.T, R23.1
/Audio Out/R: C10.2, J10.R, R27.1
/Composite/CVBS: C16.2, J15.1
/GP1_DATA: D5.1 (K), JP2.3, R12.1
/GP2_DATA: D6.1 (K), JP2.4, R13.1
/GPIO0: D1.1 (K), J1.2, R5.2, U4.1 (GPIO0)
/GPIO1: D2.1 (K), J1.3, R6.2, U4.2 (GPIO1)
/GPIO2: J5.P5 (CLK), J6.5 (CLK), U4.4 (GPIO2)
/GPIO3: J5.P3 (CMD), J6.3 (CMD), U4.5 (GPIO3)
/GPIO4: J5.P7 (DAT0), J6.7 (DAT0), U4.6 (GPIO4)
/GPIO5: J5.P2 (CD/DAT3), J6.2 (DAT3/CD), U4.7 (GPIO5)
/GPIO6: J14.7, R14.2, R42.1, R57.1, U4.9 (GPIO6)
/GPIO7: R15.2, R39.1, R55.1, U4.10 (GPIO7)
/GPIO8: J14.5, R16.2, R41.1, R49.1, U4.11 (GPIO8)
/GPIO9: J14.8, R17.2, R38.1, R47.1, U4.12 (GPIO9)
/GPIO10: J14.6, R18.2, R40.1, R53.1, U4.14 (GPIO10)
/GPIO11: R19.2, R37.1, R51.1, U4.15 (GPIO11)
/GPIO12: J14.4, R20.2, R43.2, R45.1, U4.16 (GPIO12)
/GPIO13: J14.3, R21.2, R44.2, U4.17 (GPIO13)
/GPIO14: J7.4, J8.4, JP2.19, U4.19 (GPIO14)
/GPIO15: J7.3, J8.3, JP2.20, U4.20 (GPIO15)
/GPIO16: JP2.14, JP2.18, U4.21 (GPIO16)
/GPIO17: JP2.13, JP2.17, U4.22 (GPIO17)
/GPIO18: JP2.12, U2.1 (~CE), U4.24 (GPIO18)
/GPIO19: JP2.11, U2.6 (SCLK), U4.25 (GPIO19)
/GPIO20: U2.5 (SI/SIO), U4.26 (GPIO20)
/GPIO21: JP2.16, U4.27 (GPIO21)
/GPIO22: JP1.7, U4.29 (GPIO22)
/GPIO26: JP1.11, U3.3 (DATA), U4.31 (GPIO26_ADC0)
/GPIO27: JP1.12, U3.1 (SCLK), U4.32 (GPIO27_ADC1)
/GPIO28: JP1.10, U3.2 (LRCK), U4.34 (GPIO28_ADC2)
/KB_CLK: J4.5, R4.2, R5.1, U5.13 (12)
/KB_DATA: J4.1, R6.1, R7.2, U5.12 (11)
/LOAD_IN_D: JP1.6, Q1.3 (C), R29.2
/MS_CLK: J4.6, R9.2, R11.1, U5.16 (15)
/MS_CLK_3V: D4.1 (K), JP2.2, R11.2
/MS_DATA: J4.2, R8.2, R10.1, U5.15 (14)
/MS_DATA_3V: D3.1 (K), JP2.1, R10.2
/Micro SD/DAT1: J5.P8 (DAT1), J6.8 (DAT1)
/Micro SD/DAT2: J5.P1 (DAT2), J6.1 (DAT2)
/PSR_SOSIO: JP2.5, JP3.2 (B)
/Power/D+: J3.6 (DP1), J3.8 (DP2)
/Power/D-: J3.5 (DN2), J3.7 (DN1)
/RS232/C1+: C18.2, U6.1 (C1+)
/RS232/C1-: C18.1, U6.3 (C1-)
/RS232/C2+: C19.2, U6.4 (C2+)
/RS232/C2-: C19.1, U6.5 (C2-)
/RS232/CTS_IN: J16.7, U6.7 (T2OUT)
/RS232/CTS_MAX: D8.1 (K), U6.9 (R2OUT)
/RS232/RTS_IN: J16.8, U6.8 (R2IN)
/RS232/RX_IN: J16.3, U6.14 (T1OUT)
/RS232/RX_MAX: D9.1 (K), U6.12 (R1OUT)
/RS232/TX_IN: J16.2, U6.13 (R1IN)
/RS232/V+: C17.1, U6.2 (V+)
/RS232/V-: C20.1, U6.6 (V-)
/RS232_CTS: D8.2 (A), JP2.9, R59.1
/RS232_RTS: JP2.10, U6.10 (T2IN)
/RS232_RX: D9.2 (A), JP2.8, R60.1
/RS232_TX: JP2.7, U6.11 (T1IN)
/RUN: S1.1, U4.30 (RUN)
/USB_D1M: R35.1, U5.4 (3)
/USB_D1P: R33.1, U5.3 (2)
/USB_D2M: R36.1, U5.6 (5)
/USB_D2P: R34.1, U5.5 (4)
/ZERO_VBUS: JP2.6, U5.23 (5V)
GND: C1.2, C2.2, C3.2, C4.1, C5.2, C6.2, C8.2, C9.2, C11.2, C12.2, C14.2, C15.2, C20.2, D1.2 (A), D2.2 (A), D3.2 (A), D4.2 (A), D5.2 (A), D6.2 (A), J1.1, J2.2, J3.1 (GND), J3.12 (GND), J3.13 (SHIELD), J4.3, J5.G1 (GND_1), J5.G2 (GND_2), J5.G3 (GND_3), J5.P6 (VSS), J6.6 (VSS), J7.8, J8.8, J9.2 (G_D2), J9.5 (G_D1), J9.8 (G_D0), J9.11 (G_CLK), J9.17 (G_DDC/CEC), J9.20 (SHIELD1), J9.21 (SHIELD2), J9.22 (SHIELD3), J9.23 (SHIELD4), J10.S, J11.S, J12.4 (GND1), J12.8 (GND2), J12.9 (Shield), J13.0, J13.5, J13.6, J13.7, J13.8, J13.10, J14.1, J15.2, J16.5, LD1.1 (K), Q1.2 (E), Q2.2 (E), R1.1, R2.1, R23.2, R27.2, R32.2, R58.1, S1.2, U1.1 (GND), U2.4 (VSS), U3.4 (AGND), U4.3 (GND), U4.8 (GND), U4.13 (GND), U4.18 (GND), U4.23 (GND), U4.28 (GND), U4.33 (AGND), U4.38 (GND), U5.22 (GND), U6.15 (GND)
unnamed: C7.1, C8.1, R22.1, R24.1
unnamed: C10.1, C11.1, R25.1, R26.1
unnamed: C13.1, J11.T, R32.1
unnamed: C13.2, R31.1
unnamed: C16.1, R46.2
unnamed: D7.2 (A), Q2.3 (C), R28.2, R30.1
unnamed: D7.1 (K), Q2.1 (B), R31.2
unnamed: J3.4 (CC1), R1.2
unnamed: J3.10 (CC2), R2.2
unnamed: J7.2, R12.2
unnamed: J8.2, R13.2
unnamed: J9.12 (CLKN), R14.1
unnamed: J9.10 (CLKP), R15.1
unnamed: J9.9 (D0N), R16.1
unnamed: J9.7 (D0P), R17.1
unnamed: J9.6 (D1N), R18.1
unnamed: J9.4 (D1P), R19.1
unnamed: J9.3 (D2N), R20.1
unnamed: J9.1 (D2P), R21.1
unnamed: J12.3 (D1+), R33.2
unnamed: J12.2 (D1-), R35.2
unnamed: J12.7 (D2+), R34.2
unnamed: J12.6 (D2-), R36.2
unnamed: J13.1, R37.2, R40.2
unnamed: J13.2, R38.2, R41.2
unnamed: J13.3, R39.2, R42.2
unnamed: J13.13, R43.1
unnamed: J13.14, R44.1
unnamed: J16.1, J16.4, J16.6
unnamed: JP3.1 (A), U2.2 (SO/SIO)
unnamed: JP4.1 (A), U4.36 (3V3)
unnamed: LD1.2 (A), R3.1
unnamed: Q1.1 (B), R30.2
unnamed: R45.2, R46.1, R47.2, R48.2
unnamed: R48.1, R49.2, R50.2
unnamed: R50.1, R51.2, R52.2
unnamed: R52.1, R53.2, R54.2
unnamed: R54.1, R55.2, R56.2
unnamed: R56.1, R57.2, R58.2
unnamed: C9.1, U3.7 (FLT)
VBUS: C1.1, C3.1, C5.1, C14.1, C15.1, C17.2, J2.3, J3.2 (VBUS), J3.11 (VBUS), J4.4, J7.6, J8.6, J9.18 (+5V), J12.1 (VBUS1), J12.5 (VBUS2), J14.2, JP2.15, R4.1, R7.1, R8.1, R9.1, U1.3 (VI), U3.5 (VA), U4.40 (VBUS), U6.16 (VCC)

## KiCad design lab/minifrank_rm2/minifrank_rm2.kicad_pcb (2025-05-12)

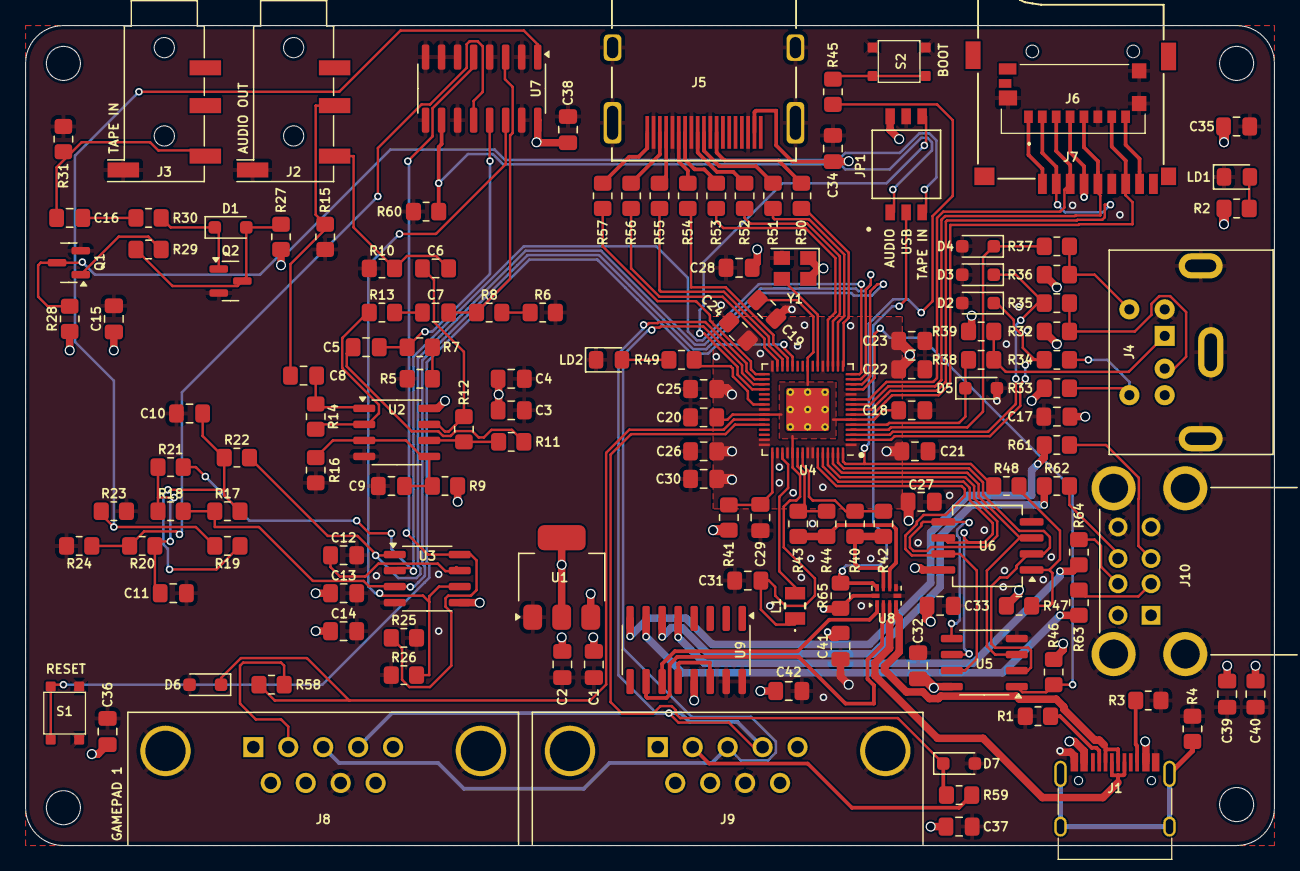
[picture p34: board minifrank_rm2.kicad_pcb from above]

Board: 4 copper layers, 99.0 x 65.0 mm, 146 parts (0 on the bottom side), 108 nets.

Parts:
C1, C2, C3, C5, C6, C7, C8, C9, C12, C13, C17, C39, C40: 10u; Capacitor (0805)
C4, C14, C15, C16, C18, C20, C21, C22, C23, C24, C25, C26, C27, C28, C32, C33, C34, C35, C36, C37, C38, C41: 100n; Capacitor (0805)
C10, C11: 47n; Capacitor (0805)
C19, C29, C30, C31, C42: 4.7u; Capacitor (0805)
D1: 1N4148; Diode (SOD-323)
D2, D3, D4, D5, D6, D7: 3V3; Diode (SOD-323)
H1, H2, H3, H4: MountingHole; Mounting Hole (2.7mm)
J1: USB4215-03-A; USB Type C
J2, J3: PJ-320D; Jack (3.5mm, PJ-320D)
J4: Mini-DIN-6; MiniDIN (6 Pin, female)
J5: HDMI Female; HDMI (female)
J6: 47571-0001; MicroSD (SMD, short)
J7: 104031-0811; MicroSD (SMD, long)
J8, J9: Gamepad; D-SUB (9 pin, male, top mount)
J10: SS-52100-004; USB Type A (stacked)
JP1: Main Jumpers; Jumper (SMD, 3 Pin)
L1: 3.3u; Inductor (0806)
LD1: Green; LED (0805)
LD2: Blue; LED (0805)
Q1, Q2: BC850; SOT-23
R1, R3: 5.1K; Resistor (0805)
R2, R21, R22, R28, R32, R33, R36, R45, R49, R58, R59: 1K; Resistor (0805)
R4: 1M; Resistor (0805)
R5, R6, R17, R18, R23, R24: 2K; Resistor (0805)
R7, R8, R9, R11, R13, R16, R19, R20, R27, R29, R30, R46, R47, R60, R65: 10K; Resistor (0805)
R10, R15: 20K; Resistor (0805)
R12, R14: 47K; Resistor (0805)
R25, R26: 470R; Resistor (0805)
R31, R34, R35, R37, R38: 100R; Resistor (0805)
R39: 1k; Resistor (0805)
R40, R43: 150R; Resistor (0805)
R41: 33; Resistor (0805)
R42, R44: 33R; Resistor (0805)
R48: 0R; Resistor (0805)
R50, R51, R52, R53, R54, R55, R56, R57: 270R; Resistor (0805)
R61, R62, R63, R64: 22R; Resistor (0805)
S1, S2: TS-1233; Button (SMD, 3x3mm, 1-1)
U1: NCP1117 3.3; SOT-223
U2: LM358; SO-8
U3: TDA1387T; SO-8
U4: RP2350; QFN 60 (RP2350A)
U5: ESP-PSRAM32; SO-8
U6: W25Q128JVS; SOIC-8
U7: 74HC4052D; SOP-16
U8: TS3USB221RSER; UQFN-10
U9: MW7211A; SOP-16
Y1: ASE-12MHz; Crystal (3225, active)

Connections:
+1V1: C18.1, C19.1, C20.1, C31.1, L1.1, U4.6 (DVDD), U4.23 (DVDD), U4.39 (DVDD), U4.50 (VREG_FB)
+3V3: C2.1, C15.1, C21.1, C22.1, C23.1, C24.1, C25.1, C26.1, C27.1, C28.1, C30.1, C32.1, C33.1, C35.2, C38.2, C41.2, J6.P4 (VDD), J7.4 (VDD), JP1.6, R2.2, R27.1, R28.1, R41.1, R46.2, R47.1, R65.1, U1.2 (VO), U4.1 (IOVDD), U4.11 (IOVDD), U4.20 (IOVDD), U4.30 (IOVDD), U4.38 (IOVDD), U4.44 (ADC_AVDD), U4.45 (IOVDD), U4.49 (VREG_VIN), U4.53 (USB_OTP_VDD), U4.54 (QSPI_IOVDD), U5.8 (VCC), U6.8 (VCC), U7.16 (VCC), U8.10 (VCC), Y1.1 (EN), Y1.4 (Vdd)
/AMP_IN_L: C5.1, R7.1, U7.13 (1Z)
/AMP_IN_R: C7.1, R8.1, U7.3 (2Z)
/AUDIOSW: JP1.1, R60.2, U7.10 (S0)
/Audio Out/AMP_OUTL: C6.2, J2.T, R10.2
/Audio Out/AMP_OUTR: C8.2, J2.R, R15.2
/D+: R40.1, R42.1, U8.8 (D+)
/D-: R43.1, R44.1, U8.7 (D-)
/DAT1: J6.P8 (DAT1), J7.8 (DAT1)
/DAT2: J6.P1 (DAT2), J7.1 (DAT2)
/GPIO0: D2.1 (K), R34.2, U4.2 (GPIO0)
/GPIO1: D3.1 (K), R35.2, U4.3 (GPIO1)
/GPIO2: D4.1 (K), R37.2, U4.4 (GPIO2)
/GPIO3: D5.1 (K), R38.2, U4.5 (GPIO3)
/GPIO4: J6.P7 (DAT0), J7.7 (DAT0), U4.7 (GPIO4)
/GPIO5: J6.P2 (CD/DAT3), J7.2 (DAT3/CD), U4.8 (GPIO5)
/GPIO6: J6.P5 (CLK), J7.5 (CLK), U4.9 (GPIO6)
/GPIO7: J6.P3 (CMD), J7.3 (CMD), U4.10 (GPIO7)
/GPIO8: R46.1, U4.12 (GPIO8), U5.1 (~CE)
/GPIO9: R17.1, R18.1, U3.3 (DATA), U4.13 (GPIO9)
/GPIO10: R22.2, U3.1 (SCLK), U4.14 (GPIO10)
/GPIO11: R21.2, U3.2 (LRCK), U4.15 (GPIO11)
/GPIO12: R50.2, U4.16 (GPIO12)
/GPIO13: R51.2, U4.17 (GPIO13)
/GPIO14: R52.2, U4.18 (GPIO14)
/GPIO15: R53.2, U4.19 (GPIO15)
/GPIO16: R54.2, U4.27 (GPIO16)
/GPIO17: R55.2, U4.28 (GPIO17)
/GPIO18: R56.2, U4.29 (GPIO18)
/GPIO19: R57.2, U4.31 (GPIO19)
/GPIO20: J8.4, J9.4, U4.32 (GPIO20)
/GPIO21: J8.3, J9.3, U4.33 (GPIO21)
/GPIO22: JP1.4, U4.34 (GPIO22)
/GPIO26: D6.1 (K), R58.1, U4.40 (GPIO26_ADC0)
/GPIO27: D7.1 (K), R59.1, U4.41 (GPIO27_ADC1)
/Gamepad 1/J_DATA: J8.2, R58.2
/Gamepad 2/J_DATA: J9.2, R59.2
/HUB_D+: U8.1 (1D+), U9.11 (DPU)
/HUB_D-: U8.2 (1D-), U9.10 (DMU)
/LOAD_IN: JP1.3, Q1.3 (C), R28.2
/PS2/PS/2 CLK: J4.5, R36.2, R37.1
/PS2/PS/2 DATA: J4.1, R38.1, R39.2
/PWM_OUT_L: R20.2, R24.1, U7.12 (1Y0)
/PWM_OUT_R: R19.2, R23.1, U7.1 (2Y0)
/RP2350A/FLASH_SS: R47.2, R48.2, U6.1 (~CS)
/RP2350A/QSPI_SCLK: U4.56 (QSPI_SCLK), U5.6 (SCLK), U6.6 (CLK)
/RP2350A/QSPI_SD0: U4.57 (QSPI_SD0), U5.5 (SI/SIO), U6.5 (DI(IO0))
/RP2350A/QSPI_SD1: U4.59 (QSPI_SD1), U5.2 (SO/SIO), U6.2 (DO(IO1))
/RP2350A/QSPI_SD2: U4.58 (QSPI_SD2), U5.3 (SIO2), U6.3 (IO2)
/RP2350A/QSPI_SD3: U4.55 (QSPI_SD3), U5.7 (SIO3), U6.7 (IO3)
/RP2350A/QSPI_SS: R45.1, R48.1, U4.60 (QSPI_SS)
/RP2350A/VREG_AVDD: C29.1, R41.2, U4.46 (VREG_AVDD)
/RP2350A/VREG_LX: L1.2, U4.48 (VREG_LX)
/RP2350A/XIN: U4.21 (XIN), Y1.3 (OUT)
/RP2350A/~USB_BOOT: R45.2, S2.2
/RUN: S1.1, U4.26 (RUN)
/TDA_L: R26.2, U3.6 (A_LEFT), U7.14 (1Y1)
/TDA_R: R25.1, U3.8 (A_RIGHT), U7.5 (2Y1)
/USBMPXSW: JP1.2, R65.2, U8.9 (S)
/USB_D1+: R61.1, U9.8 (DP3)
/USB_D1-: R63.1, U9.7 (DM3)
/USB_D2+: R62.1, U9.6 (DP2)
/USB_D2-: R64.1, U9.5 (DM2)
/UTC_D+: J1.6 (DP1), J1.8 (DP2), U8.3 (2D+)
/UTC_D-: J1.5 (DN2), J1.7 (DN1), U8.4 (2D-)
GND: C1.2, C2.2, C3.1, C4.1, C9.1, C10.2, C11.2, C12.2, C13.2, C14.2, C15.2, C17.2, C18.2, C19.2, C20.2, C21.2, C22.2, C23.2, C24.2, C25.2, C26.2, C27.2, C28.2, C29.2, C30.2, C31.2, C32.2, C33.2, C34.2, C35.1, C36.2, C37.2, C38.1, C39.2, C40.2, C41.1, C42.2, D2.2 (A), D3.2 (A), D4.2 (A), D5.2 (A), D6.2 (A), D7.2 (A), J1.1 (GND), J1.12 (GND), J2.S, J3.S, J4.3, J5.2 (G_D2), J5.5 (G_D1), J5.8 (G_D0), J5.11 (G_CLK), J5.17 (G_DDC/CEC), J5.20 (SHIELD1), J5.21 (SHIELD2), J5.22 (SHIELD3), J5.23 (SHIELD4), J6.G1 (GND_1), J6.G2 (GND_2), J6.G3 (GND_3), J6.P6 (VSS), J7.6 (VSS), J8.8, J9.8, J10.4 (GND1), J10.8 (GND2), J10.9 (Shield), JP1.5, LD1.1 (K), LD2.1 (K), Q1.2 (E), Q2.2 (E), R1.1, R3.1, R4.2, R5.2, R6.2, R10.1, R15.1, R16.1, R23.2, R24.2, R25.2, R26.1, R31.2, R60.1, S1.2, S2.1, U1.1 (GND), U2.4 (V-), U3.4 (AGND), U4.47 (VREG_PGND), U4.61 (GND), U5.4 (VSS), U6.4 (GND), U7.2 (2Y2), U7.4 (2Y3), U7.6 (~E), U7.7 (VEE), U7.8 (GND), U7.9 (S1), U7.11 (1Y3), U7.15 (1Y2), U8.5 (GND), U8.6 (~OE), U9.15 (GND), U9.16 (GND), Y1.2 (GND)
GPIO25: R49.2, U4.37 (GPIO25)
unnamed: C5.2, R11.2
unnamed: C6.1, R12.1, U2.7
unnamed: C7.2, R13.2
unnamed: C8.1, R14.1, U2.1
unnamed: C10.1, R17.2, R19.1, R22.1
unnamed: C11.1, R18.2, R20.1, R21.1
unnamed: C16.1, J3.T, R31.1
unnamed: C16.2, R30.1
unnamed: D1.2 (A), Q2.3 (C), R27.2, R29.1
unnamed: D1.1 (K), Q2.1 (B), R30.2
unnamed: J1.4 (CC1), R1.2
unnamed: J1.10 (CC2), R3.2
unnamed: J1.13 (SHIELD), R4.1
unnamed: J4.2, R32.2, R35.1
unnamed: J4.6, R33.2, R34.1
unnamed: J5.12 (CLKN), R50.1
unnamed: J5.10 (CLKP), R51.1
unnamed: J5.9 (D0N), R52.1
unnamed: J5.7 (D0P), R53.1
unnamed: J5.6 (D1N), R54.1
unnamed: J5.4 (D1P), R55.1
unnamed: J5.3 (D2N), R56.1
unnamed: J5.1 (D2P), R57.1
unnamed: J10.3 (D1+), R61.2
unnamed: J10.2 (D1-), R63.2
unnamed: J10.7 (D2+), R62.2
unnamed: J10.6 (D2-), R64.2
unnamed: LD1.2 (A), R2.1
unnamed: LD2.2 (A), R49.1
unnamed: Q1.1 (B), R29.2
unnamed: R5.1, R7.2
unnamed: R6.1, R8.2
unnamed: C9.2, R9.1, R16.2, U2.3 (+), U2.5 (+)
unnamed: R13.1, R14.2, U2.2 (-)
unnamed: R11.1, R12.2, U2.6 (-)
unnamed: C12.1, U3.7 (FLT)
unnamed: R43.2, R44.2, U4.51 (USB_DM)
unnamed: R40.2, R42.2, U4.52 (USB_DP)
unnamed: U9.12 (VD33), U9.14 (VD3)
VBUS: C1.1, C3.2, C4.2, C13.1, C14.1, C17.1, C34.1, C36.1, C37.1, C39.1, C40.1, C42.1, J1.2 (VBUS), J1.11 (VBUS), J4.4, J5.18 (+5V), J8.6, J9.6, J10.1 (VBUS1), J10.5 (VBUS2), R9.2, R32.1, R33.1, R36.1, R39.1, U1.3 (VI), U2.8 (V+), U3.5 (VA), U9.13 (VDD5)

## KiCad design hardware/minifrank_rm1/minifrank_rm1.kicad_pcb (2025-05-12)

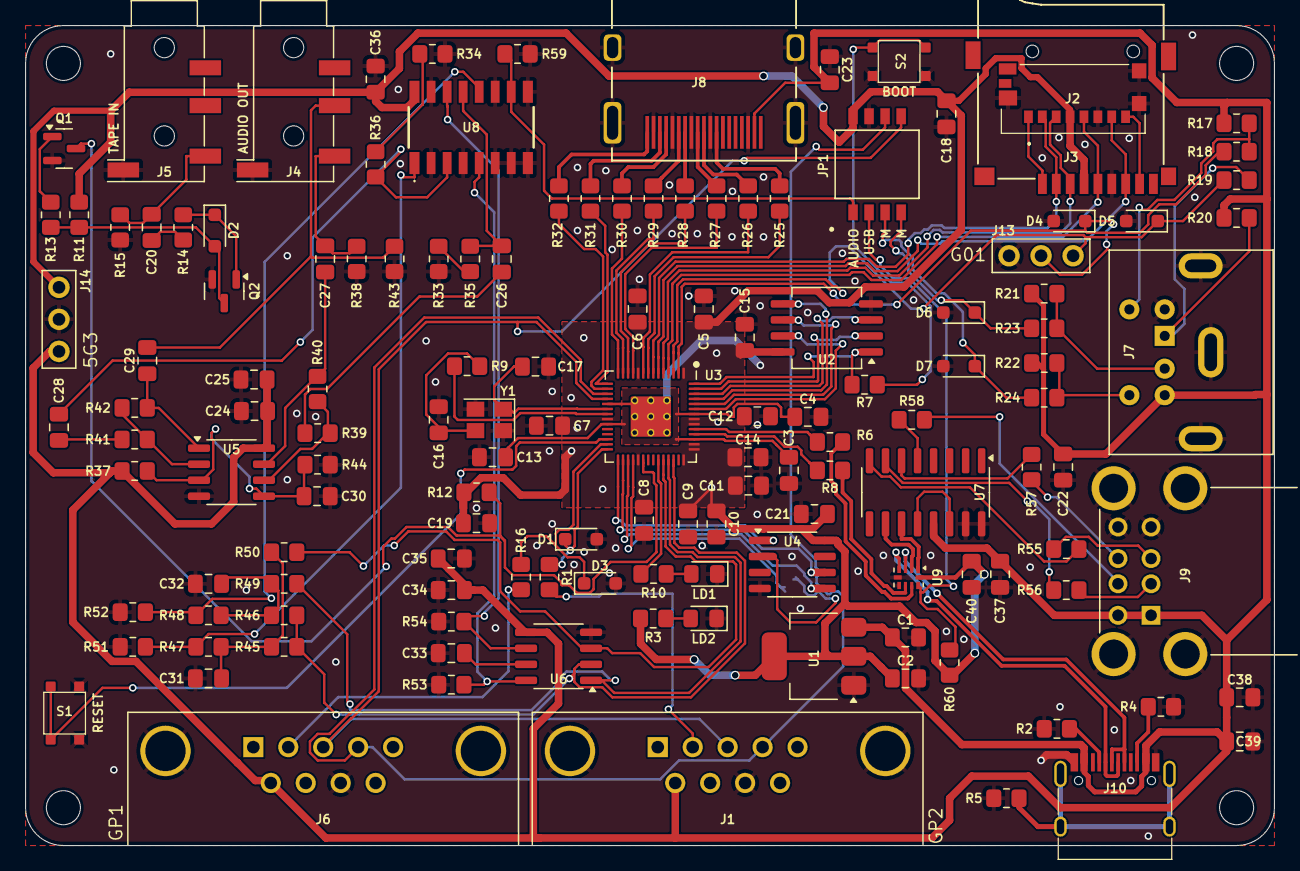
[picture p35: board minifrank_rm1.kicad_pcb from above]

Board: 2 copper layers, 99.0 x 65.0 mm, 141 parts (1 on the bottom side), 110 nets.

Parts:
C1, C2, C24, C26, C27, C28, C29, C30, C33, C34, C38, C39: 10u; Capacitor (0805)
C3, C4, C5, C6, C7, C8, C9, C10, C11, C12, C15, C18, C19, C20, C21, C22, C23, C25, C35, C36, C40: 100n; Capacitor (0805)
C13, C14: 1u; Capacitor (0805)
C16, C17: 15p; Capacitor (0805)
C31, C32: 47n; Capacitor (0805)
C37: 4.7u; Capacitor (0805)
D1, D3, D4, D5, D6, D7: 3V3; Diode (SOD-323)
D2: 1N4148; Diode (SOD-323)
H1, H2, H3, H4: MountingHole; Mounting Hole (2.7mm)
J1, J6: D-SUB 9 Male; D-SUB (9 pin, male, top mount)
J2: 0475710001; MicroSD (SMD, short)
J3: 104031-0811; MicroSD (SMD, long)
J4, J5: PJ-320D; Jack (3.5mm, PJ-320D)
J7: MDC-036; MiniDIN (6 Pin, female)
J8: DC3RX19JA2; HDMI (female)
J9: SS-52100-004; USB Type A (stacked)
J10: USB4215-03-A; USB Type C
J13: UART; Pin Header (1x03)
J14: PWR; Pin Header (1x03)
JP1: Main Jumpers; SW_DS05-127-2-04BK-SMT-TR
JP2: Jumper (Solder); Jumper (solder)
LD1: Blue; LED (0805)
LD2: Green; LED (0805)
Q1, Q2: BC850; SOT-23
R1, R3, R7, R9, R10, R12, R16, R17, R20, R21, R22, R49, R50: 1K; Resistor (0805)
R2, R4: 5.1K; Resistor (0805)
R5: 1M; Resistor (0805)
R6, R8: 27R; Resistor (0805)
R11, R13, R14, R35, R36, R37, R39, R41, R44, R47, R48, R59, R60: 10K; Resistor (0805)
R15, R18, R19, R23, R24: 100R; Resistor (0805)
R25, R26, R27, R28, R29, R30, R31, R32: 270R; Resistor (0805)
R33, R34, R45, R46, R51, R52: 2K; Resistor (0805)
R38, R43: 20K; Resistor (0805)
R40, R42: 47K; Resistor (0805)
R53, R54: 470R; Resistor (0805)
R55, R56, R57, R58: 22R; Resistor (0805)
S1: Reset; Button (SMD, 3x3mm, 1-1)
S2: Boot; Button (SMD, 3x3mm, 1-1)
U1: NCP1117 3.3; SOT-223
U2: W25Q128JVSIQ; SOIC-8
U3: RP2040; QFN 56
U4: ESP-PSRAM32; SO-8
U5: LM358; SO-8
U6: TDA1387T; SO-8
U7: MW7211A; SOP-16
U8: 74HC4052D; 74HC4052D653
U9: TS3USB221RSER; UQFN-10
Y1: 12 MHz; Crystal (3225)

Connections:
+3V3: C2.1, C5.1, C6.1, C7.1, C8.1, C9.1, C10.1, C11.1, C12.1, C14.1, C15.1, C18.2, C19.1, C21.1, C36.2, C40.2, J2.P4 (VDD), J3.4 (VDD), J14.1, JP1.8, R3.2, R11.1, R12.1, R60.1, U1.2 (VO), U2.8 (VCC), U3.1 (IOVDD), U3.10 (IOVDD), U3.22 (IOVDD), U3.33 (IOVDD), U3.42 (IOVDD), U3.43 (ADC_AVDD), U3.44 (VREG_IN), U3.48 (USB_VDD), U3.49 (IOVDD), U4.8 (VCC), U8.16 (VCC), U9.10 (VCC)
/AMP_IN_L: C26.1, R35.1, U8.13 (1Z)
/AMP_IN_R: C28.1, R36.1, U8.3 (2Z)
/AUDIOSW: JP1.1, R59.2, U8.10 (S0)
/Audio Out/AMP_OUTL: C27.2, J4.T, R38.2
/Audio Out/AMP_OUTR: C29.2, J4.R, R43.2
/D+: R6.1, U9.8 (D+)
/D-: R8.1, U9.7 (D-)
/GPIO0: D4.1 (K), J13.2, R18.2, U3.2 (GPIO0)
/GPIO1: D5.1 (K), J13.3, R19.2, U3.3 (GPIO1)
/GPIO2: J2.P5 (CLK), J3.5 (CLK), U3.4 (GPIO2)
/GPIO3: J2.P3 (CMD), J3.3 (CMD), U3.5 (GPIO3)
/GPIO4: J2.P7 (DAT0), J3.7 (DAT0), U3.6 (GPIO4)
/GPIO5: J2.P2 (CD/DAT3), J3.2 (DAT3/CD), U3.7 (GPIO5)
/GPIO6: R25.2, U3.8 (GPIO6)
/GPIO7: R26.2, U3.9 (GPIO7)
/GPIO8: R27.2, U3.11 (GPIO8)
/GPIO9: R28.2, U3.12 (GPIO9)
/GPIO10: R29.2, U3.13 (GPIO10)
/GPIO11: R30.2, U3.14 (GPIO11)
/GPIO12: R31.2, U3.15 (GPIO12)
/GPIO13: R32.2, U3.16 (GPIO13)
/GPIO14: J1.4, J6.4, JP1.6, U3.17 (GPIO14)
/GPIO15: J1.3, J6.3, JP1.5, U3.18 (GPIO15)
/GPIO16: D3.1 (K), R16.1, U3.27 (GPIO16)
/GPIO17: D1.1 (K), R1.1, U3.28 (GPIO17)
/GPIO18: U3.29 (GPIO18), U4.1 (~CE)
/GPIO19: U3.30 (GPIO19), U4.6 (SCLK)
/GPIO20: U3.31 (GPIO20), U4.5 (SI/SIO)
/GPIO21: JP2.2 (B), U3.32 (GPIO21)
/GPIO22: Q1.3 (C), R12.2, U3.34 (GPIO22)
/GPIO26: R50.2, U3.38 (GPIO26_ADC0), U6.3 (DATA)
/GPIO27: R49.2, U3.39 (GPIO27_ADC1), U6.1 (SCLK)
/GPIO28: R45.1, R46.1, U3.40 (GPIO28_ADC2), U6.2 (LRCK)
/HUB_D+: U7.11 (DPU), U9.1 (1D+)
/HUB_D-: U7.10 (DMU), U9.2 (1D-)
/KB_CLK: J7.5, R17.2, R18.1
/KB_DATA: J7.1, R19.1, R20.2
/MS_CLK: J7.6, R22.2, R24.1
/MS_CLK_3V: D7.1 (K), JP1.3, R24.2
/MS_DATA: J7.2, R21.2, R23.1
/MS_DATA_3V: D6.1 (K), JP1.4, R23.2
/PWM_OUT_L: R48.2, R52.1, U8.12 (1Y0)
/PWM_OUT_R: R47.2, R51.1, U8.1 (2Y0)
/RP2040/GPIO25: R10.2, U3.37 (GPIO25)
/RP2040/QSPI_SCLK: U2.6 (CLK), U3.52 (QSPI_SCLK)
/RP2040/QSPI_SD0: U2.5 (DI(IO0)), U3.53 (QSPI_SD0)
/RP2040/QSPI_SD1: U2.2 (DO(IO1)), U3.55 (QSPI_SD1)
/RP2040/QSPI_SD2: U2.3 (IO2), U3.54 (QSPI_SD2)
/RP2040/QSPI_SD3: U2.7 (IO3), U3.51 (QSPI_SD3)
/RP2040/QSPI_SS: R7.1, U2.1 (~CS), U3.56 (QSPI_SS)
/RP2040/XIN: C17.1, U3.20 (XIN), Y1.1
/RP2040/XOUT: R9.1, U3.21 (XOUT)
/RUN: S1.1, U3.26 (RUN)
/SD Card/DAT1: J2.P8 (DAT1), J3.8 (DAT1)
/SD Card/DAT2: J2.P1 (DAT2), J3.1 (DAT2)
/TDA_L: R54.2, U6.6 (A_LEFT), U8.14 (1Y1)
/TDA_R: R53.1, U6.8 (A_RIGHT), U8.5 (2Y1)
/USBMPXSW: JP1.2, R60.2, U9.9 (S)
/USB_D1+: R55.1, U7.8 (DP3)
/USB_D1-: R56.1, U7.7 (DM3)
/USB_D2+: R57.1, U7.6 (DP2)
/USB_D2-: R58.1, U7.5 (DM2)
/UTC_D+: J10.6 (DP1), J10.8 (DP2), U9.3 (2D+)
/UTC_D-: J10.5 (DN2), J10.7 (DN1), U9.4 (2D-)
GND: C1.2, C2.2, C3.2, C4.2, C5.2, C6.2, C7.2, C8.2, C9.2, C10.2, C11.2, C12.2, C13.2, C14.2, C15.2, C16.2, C17.2, C18.1, C19.2, C21.2, C22.2, C23.2, C24.1, C25.1, C30.1, C31.2, C32.2, C33.2, C34.2, C35.2, C36.1, C37.2, C38.2, C39.2, C40.1, D1.2 (A), D3.2 (A), D4.2 (A), D5.2 (A), D6.2 (A), D7.2 (A), J1.8, J2.G1 (GND_1), J2.G2 (GND_2), J2.G3 (GND_3), J2.P6 (VSS), J3.6 (VSS), J4.S, J5.S, J6.8, J7.3, J8.2 (G_D2), J8.5 (G_D1), J8.8 (G_D0), J8.11 (G_CLK), J8.17 (G_DDC/CEC), J8.20 (SHIELD1), J8.21 (SHIELD2), J8.22 (SHIELD3), J8.23 (SHIELD4), J9.4 (GND1), J9.8 (GND2), J9.9 (Shield), J10.1 (GND), J10.12 (GND), J13.1, J14.2, JP1.7, LD1.1 (K), LD2.1 (K), Q1.2 (E), Q2.2 (E), R2.1, R4.1, R5.2, R15.2, R33.2, R34.2, R38.1, R43.1, R44.1, R51.2, R52.2, R53.2, R54.1, R59.1, S1.2, S2.2, U1.1 (GND), U2.4 (GND), U3.19 (TESTEN), U3.57 (GND), U4.4 (VSS), U5.4 (V-), U6.4 (AGND), U7.15 (GND), U7.16 (GND), U8.2 (2Y2), U8.4 (2Y3), U8.6 (~E), U8.7 (VEE), U8.8 (GND), U8.9 (S1), U8.11 (1Y3), U8.15 (1Y2), U9.5 (GND), U9.6 (~OE), Y1.2, Y1.4
unnamed: C16.1, R9.2, Y1.3
unnamed: C20.1, J5.T, R15.1
unnamed: C20.2, R14.1
unnamed: C26.2, R39.2
unnamed: C27.1, R40.1, U5.7
unnamed: C28.2, R41.2
unnamed: C29.1, R42.1, U5.1
unnamed: C31.1, R45.2, R47.1, R50.1
unnamed: C32.1, R46.2, R48.1, R49.1
unnamed: D2.2 (A), Q2.3 (C), R11.2, R13.1
unnamed: D2.1 (K), Q2.1 (B), R14.2
unnamed: J1.2, R1.2
unnamed: J6.2, R16.2
unnamed: J8.12 (CLKN), R25.1
unnamed: J8.10 (CLKP), R26.1
unnamed: J8.9 (D0N), R27.1
unnamed: J8.7 (D0P), R28.1
unnamed: J8.6 (D1N), R29.1
unnamed: J8.4 (D1P), R30.1
unnamed: J8.3 (D2N), R31.1
unnamed: J8.1 (D2P), R32.1
unnamed: J9.3 (D1+), R55.2
unnamed: J9.2 (D1-), R56.2
unnamed: J9.7 (D2+), R57.2
unnamed: J9.6 (D2-), R58.2
unnamed: J10.4 (CC1), R2.2
unnamed: J10.10 (CC2), R4.2
unnamed: J10.13 (SHIELD), R5.1
unnamed: JP2.1 (A), U4.2 (SO/SIO)
unnamed: LD1.2 (A), R10.1
unnamed: LD2.2 (A), R3.1
unnamed: Q1.1 (B), R13.2
unnamed: R7.2, S2.1
unnamed: R33.1, R35.2
unnamed: R34.1, R36.2
unnamed: R8.2, U3.46 (USB_DM)
unnamed: R6.2, U3.47 (USB_DP)
unnamed: C3.1, C4.1, C13.1, U3.23 (DVDD), U3.45 (VREG_VOUT), U3.50 (DVDD)
unnamed: C30.2, R37.1, R44.2, U5.3 (+), U5.5 (+)
unnamed: R41.1, R42.2, U5.2 (-)
unnamed: R39.1, R40.2, U5.6 (-)
unnamed: C33.1, U6.7 (FLT)
unnamed: U7.12 (VD33), U7.14 (VD3)
VBUS: C1.1, C22.1, C23.1, C24.2, C25.2, C34.1, C35.1, C37.1, C38.1, C39.1, J1.6, J6.6, J7.4, J8.18 (+5V), J9.1 (VBUS1), J9.5 (VBUS2), J10.2 (VBUS), J10.11 (VBUS), J14.3, R17.1, R20.1, R21.1, R22.1, R37.2, U1.3 (VI), U5.8 (V+), U6.5 (VA), U7.13 (VDD5)

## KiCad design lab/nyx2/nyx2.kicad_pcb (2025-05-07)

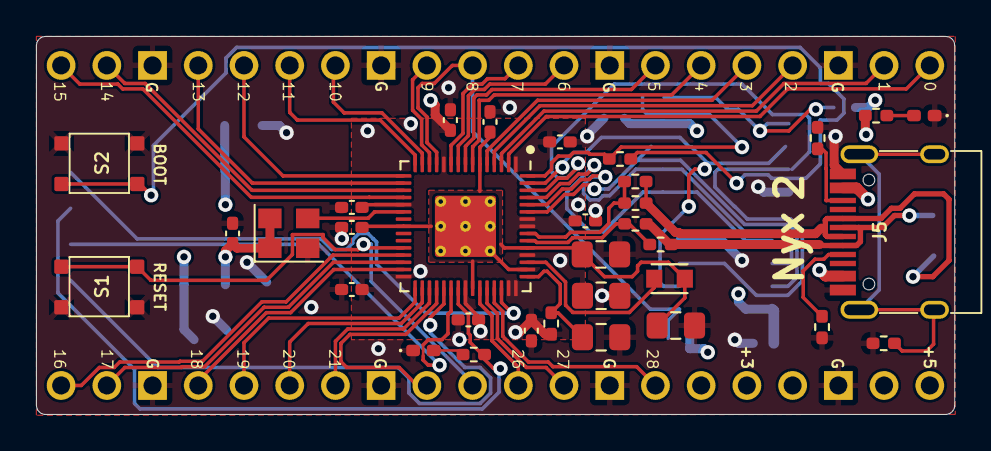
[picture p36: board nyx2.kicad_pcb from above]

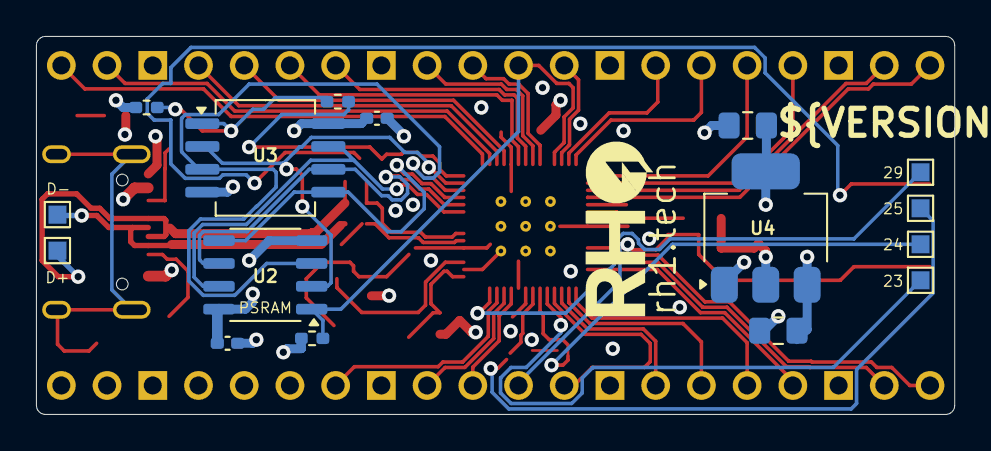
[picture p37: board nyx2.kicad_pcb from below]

Board: 4 copper layers, 51.0 x 21.0 mm, 47 parts (12 on the bottom side), 55 nets.

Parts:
C1, C3, C4, C5, C6, C7, C8, C9, C10, C11, C15, C16: 100n; Capacitor (0402)
C2, C12, C13, C14: 4.7u; Capacitor (0805)
C17, C18: 10u; Capacitor (0805)
J1: CON_PICO_21-40
J2: CON_PICO_1-20
J3: Test Points (1mm x 5)
J4: Test Points (1mm x 2)
J5: USB4215-03-A; USB Type C
L1: 3.3u; IND_LQH2MCN100K02L
LD1: Blue; LED (0402)
LD2: Green; LED (0402)
R1, R4: 150R; Resistor (0402)
R2: 33; Resistor (0402)
R3, R5: 33R; Resistor (0402)
R6, R10, R12: 1K; Resistor (0402)
R7, R8: 10K; Resistor (0402)
R9: 0R; Resistor (0402)
R11, R13: 5.1K; Resistor (0402)
R14: 1M; Resistor (0402)
S1: Reset; Button (SMD, 3x3mm, 1-1)
S2: TS-1233; Button (SMD, 3x3mm, 1-1)
U1: RP2350; QFN 60 (RP2350A)
U2: ESP-PSRAM32; SO-8
U3: W25Q128JVS; SOIC-8
U4: NCP1117 3.3; SOT-223
Y1: ASE-12MHz; Crystal (3225, active)

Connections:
+1V1: C1.1, C2.1, C3.1, C14.1, L1.1, U1.6 (DVDD), U1.23 (DVDD), U1.39 (DVDD), U1.50 (VREG_FB)
+3V3: C4.1, C5.1, C6.1, C7.1, C8.1, C9.1, C10.1, C11.1, C13.1, C15.1, C16.1, C18.1, J1.36, R2.1, R7.2, R8.1, R12.2, U1.1 (IOVDD), U1.11 (IOVDD), U1.20 (IOVDD), U1.30 (IOVDD), U1.38 (IOVDD), U1.44 (ADC_AVDD), U1.45 (IOVDD), U1.49 (VREG_VIN), U1.53 (USB_OTP_VDD), U1.54 (QSPI_IOVDD), U2.8 (VCC), U3.8 (VCC), U4.2 (VO), Y1.1 (EN), Y1.4 (Vdd)
/D+: J4.1, J5.6 (DP1), J5.8 (DP2), R1.1, R3.1
/D-: J4.2, J5.5 (DN2), J5.7 (DN1), R4.1, R5.1
/GPIO0: J2.1, U1.2 (GPIO0)
/GPIO1: J2.2, U1.3 (GPIO1)
/GPIO2: J2.4, U1.4 (GPIO2)
/GPIO3: J2.5, U1.5 (GPIO3)
/GPIO4: J2.6, U1.7 (GPIO4)
/GPIO5: J2.7, U1.8 (GPIO5)
/GPIO6: J2.9, U1.9 (GPIO6)
/GPIO7: J2.10, U1.10 (GPIO7)
/GPIO8: J2.11, R7.1, U1.12 (GPIO8), U2.1 (~CE)
/GPIO9: J2.12, U1.13 (GPIO9)
/GPIO10: J2.14, U1.14 (GPIO10)
/GPIO11: J2.15, U1.15 (GPIO11)
/GPIO12: J2.16, U1.16 (GPIO12)
/GPIO13: J2.17, U1.17 (GPIO13)
/GPIO14: J2.19, U1.18 (GPIO14)
/GPIO15: J2.20, U1.19 (GPIO15)
/GPIO16: J1.21, U1.27 (GPIO16)
/GPIO17: J1.22, U1.28 (GPIO17)
/GPIO18: J1.24, U1.29 (GPIO18)
/GPIO19: J1.25, U1.31 (GPIO19)
/GPIO20: J1.26, U1.32 (GPIO20)
/GPIO21: J1.27, U1.33 (GPIO21)
/GPIO22: J1.29, U1.34 (GPIO22)
/GPIO23: J3.1, U1.35 (GPIO23)
/GPIO24: J3.2, U1.36 (GPIO24)
/GPIO26: J1.31, U1.40 (GPIO26_ADC0)
/GPIO27: J1.32, U1.41 (GPIO27_ADC1)
/GPIO28: J1.34, U1.42 (GPIO28_ADC2)
/GPIO29: J3.4, U1.43 (GPIO29_ADC3)
/RP2350A/FLASH_SS: R8.2, R9.2, U3.1 (~CS)
/RP2350A/QSPI_SCLK: U1.56 (QSPI_SCLK), U2.6 (SCLK), U3.6 (CLK)
/RP2350A/QSPI_SD0: U1.57 (QSPI_SD0), U2.5 (SI/SIO), U3.5 (DI(IO0))
/RP2350A/QSPI_SD1: U1.59 (QSPI_SD1), U2.2 (SO/SIO), U3.2 (DO(IO1))
/RP2350A/QSPI_SD2: U1.58 (QSPI_SD2), U2.3 (SIO2), U3.3 (IO2)
/RP2350A/QSPI_SD3: U1.55 (QSPI_SD3), U2.7 (SIO3), U3.7 (IO3)
/RP2350A/QSPI_SS: R6.1, R9.1, U1.60 (QSPI_SS)
/RP2350A/VREG_AVDD: C12.1, R2.2, U1.46 (VREG_AVDD)
/RP2350A/VREG_LX: L1.2, U1.48 (VREG_LX)
/RP2350A/XIN: U1.21 (XIN), Y1.3 (OUT)
/RP2350A/~USB_BOOT: R6.2, S2.2
/RUN: J1.30, S1.1, U1.26 (RUN)
GND: C1.2, C2.2, C3.2, C4.2, C5.2, C6.2, C7.2, C8.2, C9.2, C10.2, C11.2, C12.2, C13.2, C14.2, C15.2, C16.2, C17.2, C18.2, J1.23, J1.28, J1.33, J1.38, J2.3, J2.8, J2.13, J2.18, J5.1 (GND), J5.12 (GND), LD1.1 (K), LD2.1 (K), R11.1, R13.1, R14.2, S1.2, S2.1, U1.47 (VREG_PGND), U1.61 (GND), U2.4 (VSS), U3.4 (GND), U4.1 (GND), Y1.2 (GND)
GPIO25: J3.3, R10.2, U1.37 (GPIO25)
unnamed: J5.4 (CC1), R11.2
unnamed: J5.10 (CC2), R13.2
unnamed: J5.13 (SHIELD), R14.1
unnamed: LD1.2 (A), R10.1
unnamed: LD2.2 (A), R12.1
unnamed: R4.2, R5.2, U1.51 (USB_DM)
unnamed: R1.2, R3.2, U1.52 (USB_DP)
VBUS: C17.1, J1.40, J5.2 (VBUS), J5.11 (VBUS), U4.3 (VI)

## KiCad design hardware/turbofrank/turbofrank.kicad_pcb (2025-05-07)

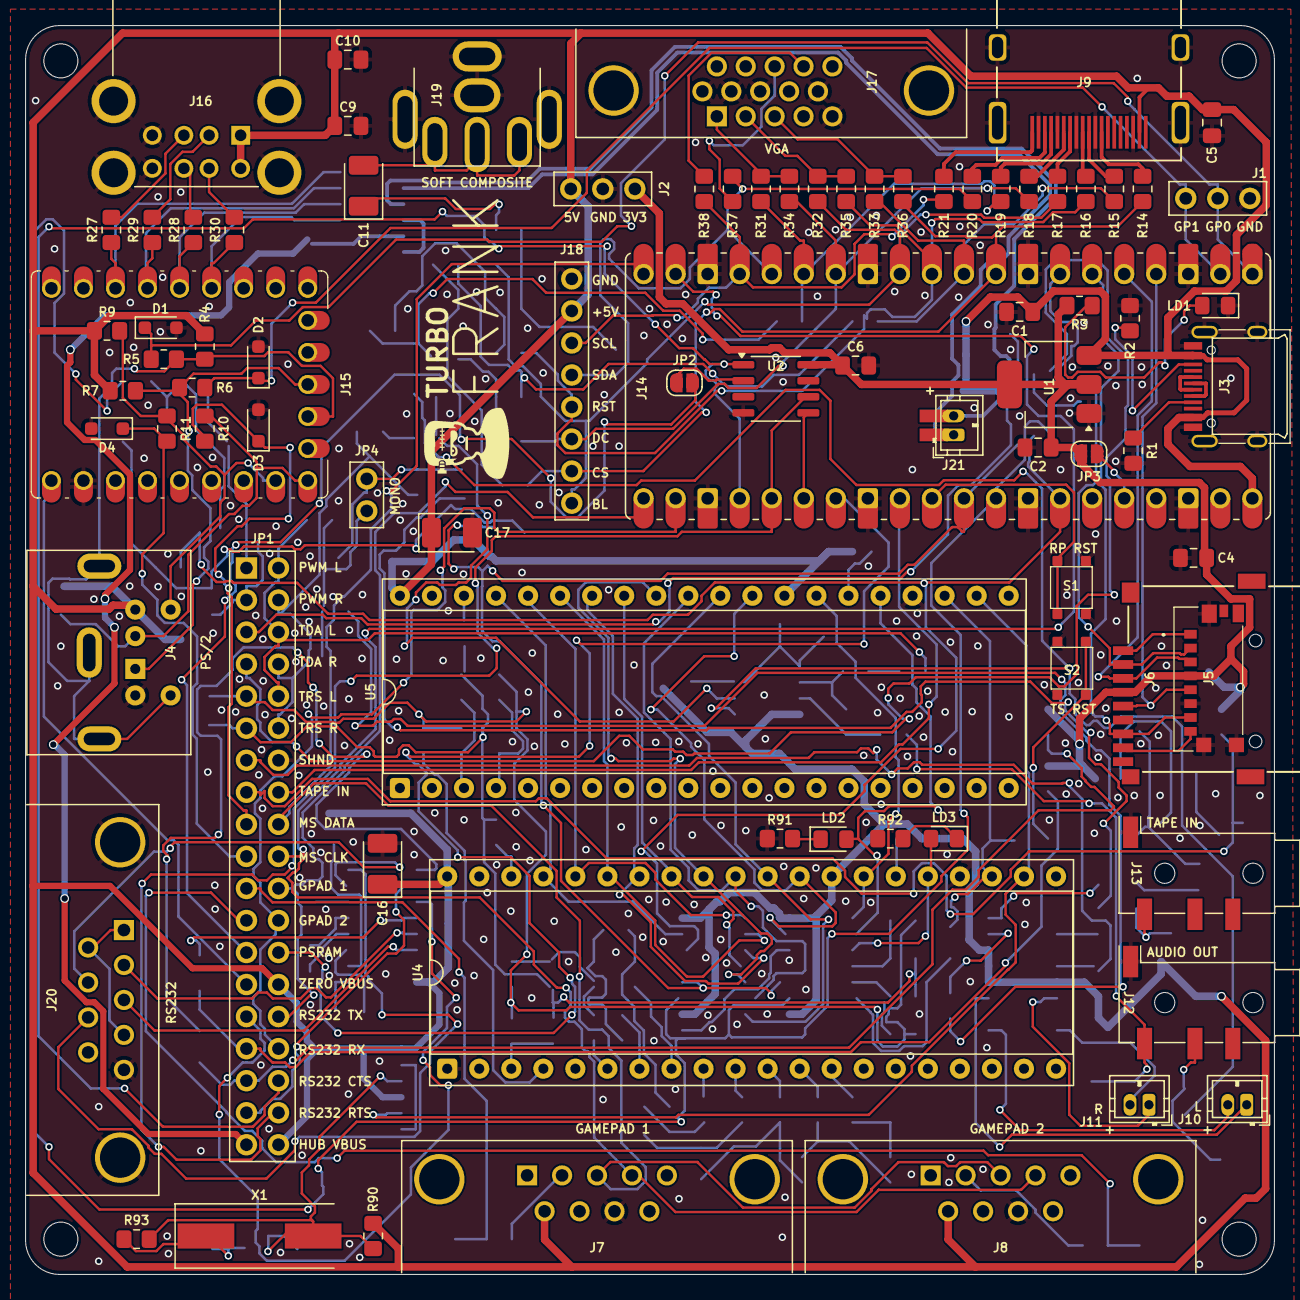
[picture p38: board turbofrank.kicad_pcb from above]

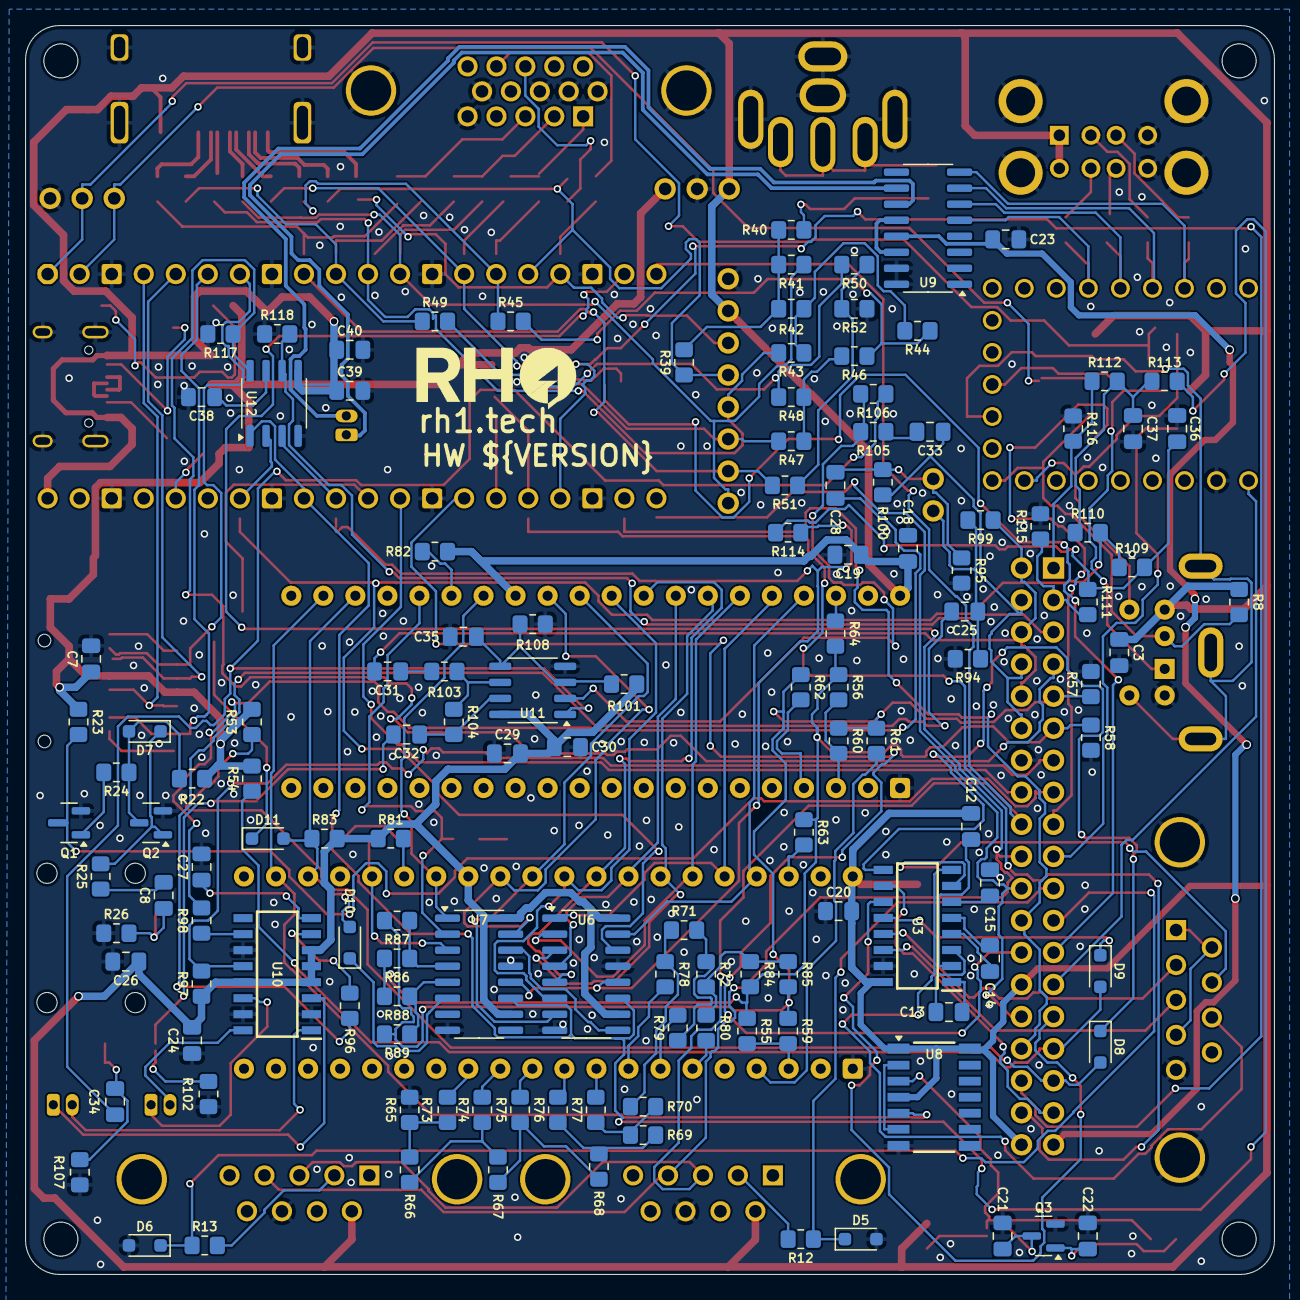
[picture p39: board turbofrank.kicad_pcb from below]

Board: 2 copper layers, 99.0 x 99.0 mm, 219 parts (132 on the bottom side), 187 nets.

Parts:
C1, C2, C9, C10, C29, C31, C32, C33, C34, C35, C38, C39: 10u; Capacitor (0805)
C3, C4, C5, C6, C7, C8, C18, C19, C20, C27, C30, C40: 100n; Capacitor (0805)
C11: 220u; Capacitor (3528, tantalum, polar)
C12, C13, C14, C15, C24, C25, C28: 1u; Capacitor (0805)
C16, C17: 100u; Capacitor (3528, tantalum, polar)
C21, C22: 22p; Capacitor (0805)
C23: 4.7u; Capacitor (0805)
C26: 47u; Capacitor (0805)
C36, C37: 47n; Capacitor (0805)
D1, D2, D3, D4, D5, D6: 3V3; Diode (SOD-323)
D7, D8, D9, D10, D11: 1N4148; Diode (SOD-323)
H1, H2, H3, H4: Hole 2.7mm; Mounting Hole (2.7mm)
J1: UART; Pin Header (1x03)
J2: PWR; Pin Header (1x03)
J3: USB4215; USB Type C
J4: MDC-036; MiniDIN (6 Pin, female)
J5: 0475710001; MicroSD (SMD, short)
J6: 104031-0811; MicroSD (SMD, long)
J7, J8, J20: D-SUB 9 Male; D-SUB (9 pin, male, top mount)
J9: DC3RX19JA2; HDMI (female)
J10: PAM L; Connector Female ZH 1.50mm (2 pins)
J11: PAM R; Connector Female ZH 1.50mm (2 pins)
J12, J13: PJ-320D; Jack (3.5mm, PJ-320D)
J14: Rasberry Pi Pico; Raspberry Pi Pico
J15: RP2040-Zero; Raspberry Pi Zero
J16: SS-52100-004; USB Type A (stacked)
J17: D-SUB 15 Female; D-SUB (15 pin, female)
J18: Pin Header 1x08; Pin Header (1x08)
J19: RCA-103; RCA
J21: USB HUB Data; Connector Female ZH 1.50mm (2 pins + tracks)
JP1: Main Jumper Set; Pin Header (2x19)
JP2, JP3: Jumper (Solder); Jumper (solder)
JP4: Mono; Pin Header (1x02)
LD1: Green; LED (0805)
LD2, LD3: Orange; LED (0805)
Q1, Q2, Q3: BC850; SOT-23
R1, R2: 5.1K; Resistor (0805)
R3, R4, R7, R8, R9, R12, R13, R23, R34, R35, R36, R53, R54, R66, R67, R68, R69, R70, R71, R72, R81, R82, R90, R91, R92, R113, R114: 1K; Resistor (0805)
R5, R6, R10, R11, R26, R37, R38: 100R; Resistor (0805)
R14, R15, R16, R17, R18, R19, R20, R21, R41, R43, R45, R47, R49, R51: 270R; Resistor (0805)
R22, R24, R25, R83, R84, R85, R86, R87, R88, R89, R96, R97, R98, R99, R100, R101, R103, R105, R108, R111, R112: 10K; Resistor (0805)
R27, R28, R29, R30: 22R; Resistor (0805)
R31, R32, R33: 330R; Resistor (0805)
R39: 750R; Resistor (0805)
R40: 51R; Resistor (0805)
R42, R44, R46, R48, R50: 150R; Resistor (0805)
R52: 300R; Resistor (0805)
R55, R56, R61, R62, R65, R73, R74, R75, R76, R77, R78, R79, R80, R94, R95, R109, R110, R115, R116: 2K; Resistor (0805)
R57, R58: 120R; Resistor (0805)
R59, R60, R63, R64: 4.7K; Resistor (0805)
R93: 100K; Resistor (0805)
R102, R107: 20K; Resistor (0805)
R104, R106: 47K; Resistor (0805)
R117, R118: 470R; Resistor (0805)
S1: TS-1233; Button (SMD, 3x3mm, 1-1)
S2: KLS7-TS3302; Button (SMD, 3x3mm, 1-1)
U1: NCP1117 3.3; SOT-223
U2: ESP-PSRAM32; SO-8
U3: MAX232CSE+; SOIC127P600X175-16N
U4, U5: JFC95101; DIP-40 (Socket)
U6, U7: 74HC595; SOP-16
U8: 74HC74; 74HCT74D
U9: MW7211A; SOP-16
U10: PAM8403D; SOIC127P600X175-16N
U11: LM358; SO-8
U12: TDA1387T; SO-8
X1: 3.58 MHz; Crystal (HC49-S)

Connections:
+3V3: C2.1, C4.2, C6.1, C7.1, J2.1, J5.P4 (VDD), J6.4 (VDD), JP3.2 (B), R3.2, R22.1, R23.1, R53.2, R54.2, U1.2 (VO), U2.8 (VCC)
/AMP_IN_L: C31.1, JP1.2, JP1.6, JP1.10, R99.1
/AMP_IN_R: C33.1, JP1.4, JP1.8, JP1.12, R100.1
/Audio Out/AMP_OUTL: C32.2, J12.T, R102.2
/Audio Out/AMP_OUTR: C34.2, J12.R, R107.2
/Audio Out/AMP_PAM_OUTL_M: J10.2, U10.3 (-OUTL)
/Audio Out/AMP_PAM_OUTL_P: J10.1, U10.1 (+OUT_L)
/Audio Out/AMP_PAM_OUTR_M: J11.2, U10.14 (-OUT_R)
/Audio Out/AMP_PAM_OUTR_P: J11.1, U10.16 (+OUT_R)
/Audio Out/Amplifier/ MONO_L: C25.1, JP4.1, R94.1, R99.2
/Audio Out/Amplifier/MONO_R: C28.1, JP4.2, R95.1, R100.2
/Audio Out/TS/A1: R62.2, U5.4 (B)
/Audio Out/TS/A2: R61.2, U4.4 (B)
/Audio Out/TS/B1: R56.2, R60.2, U5.3 (A)
/Audio Out/TS/B2: R55.2, R59.2, U4.3 (A)
/Audio Out/TS/BEEP: R86.2, R87.2, U7.4 (QE)
/Audio Out/TS/C1: R64.2, U5.38 (C)
/Audio Out/TS/C2: R63.2, U4.38 (C)
/Audio Out/TS/CLK_1.75M: U4.22 (CLOCK), U5.22 (CLOCK), U8.5 (Q)
/Audio Out/TS/COVOX_OUT: R72.2, R80.1, R84.2, R85.2
/Audio Out/TS/DA0: U4.37 (DA0), U5.37 (DA0), U6.15 (QA)
/Audio Out/TS/DA1: U4.36 (DA1), U5.36 (DA1), U6.1 (QB)
/Audio Out/TS/DA2: U4.35 (DA2), U5.35 (DA2), U6.2 (QC)
/Audio Out/TS/DA3: U4.34 (DA3), U5.34 (DA3), U6.3 (QD)
/Audio Out/TS/DA4: U4.33 (DA4), U5.33 (DA4), U6.4 (QE)
/Audio Out/TS/DA5: U4.32 (DA5), U5.32 (DA5), U6.5 (QF)
/Audio Out/TS/DA6: U4.31 (DA6), U5.31 (DA6), U6.6 (QG)
/Audio Out/TS/DA7: U4.30 (DA7), U5.30 (DA7), U6.7 (QH)
/Audio Out/TS/DAC0: R73.2, U4.13 (IOB0)
/Audio Out/TS/DAC1: R74.2, U4.12 (IOB1)
/Audio Out/TS/DAC2: R75.2, U4.11 (IOB2)
/Audio Out/TS/DAC3: R76.2, U4.10 (IOB3)
/Audio Out/TS/DAC4: R77.2, U4.9 (IOB4)
/Audio Out/TS/DAC5: R78.2, U4.8 (IOB5)
/Audio Out/TS/DAC6: R79.2, U4.7 (IOB6)
/Audio Out/TS/DAC7: R80.2, U4.6 (IOB7)
/Audio Out/TS/SAVE: R88.2, R89.2, U7.5 (QF)
/Audio Out/TS/YM_BC1: U4.29 (BC1), U5.29 (BC1), U7.15 (QA)
/Audio Out/TS/YM_BDIR: U4.27 (BDIR), U5.27 (BDIR), U7.1 (QB)
/Audio Out/TS/YM_CS1: LD2.2 (A), U5.25 (A8), U7.2 (QC)
/Audio Out/TS/YM_CS2: LD3.2 (A), U4.25 (A8), U7.3 (QD)
/Audio Out/TS/YM_RST: D10.2 (A), D11.2 (A), R83.1, U4.23 (~RESET), U5.23 (~RESET)
/Audio Out/TS/YM_SEL1: R82.2, U5.26 (~SEL)
/Audio Out/TS/YM_SEL2: R81.2, U4.26 (~SEL)
/Composite/CVBS: C11.2, J19.1
/GP1_DATA: D5.1 (K), JP1.21, R12.1
/GP2_DATA: D6.1 (K), JP1.23, R13.1
/GPIO0: D1.1 (K), J1.2, J14.1 (GPIO0), R5.2
/GPIO1: D2.1 (K), J1.3, J14.2 (GPIO1), R6.2
/GPIO2: J5.P5 (CLK), J6.5 (CLK), J14.4 (GPIO2)
/GPIO3: J5.P3 (CMD), J6.3 (CMD), J14.5 (GPIO3)
/GPIO4: J5.P7 (DAT0), J6.7 (DAT0), J14.6 (GPIO4)
/GPIO5: J5.P2 (CD/DAT3), J6.2 (DAT3/CD), J14.7 (GPIO5)
/GPIO6: J14.9 (GPIO6), J18.7, R14.2, R36.1, R51.1
/GPIO7: J14.10 (GPIO7), R15.2, R33.1, R49.1
/GPIO8: J14.11 (GPIO8), J18.5, R16.2, R35.1, R43.1
/GPIO9: J14.12 (GPIO9), J18.8, R17.2, R32.1, R41.1
/GPIO10: J14.14 (GPIO10), J18.6, R18.2, R34.1, R47.1
/GPIO11: J14.15 (GPIO11), R19.2, R31.1, R45.1
/GPIO12: J14.16 (GPIO12), J18.4, R20.2, R37.2, R39.1
/GPIO13: J14.17 (GPIO13), J18.3, R21.2, R38.2
/GPIO14: J7.4, J8.4, J14.19 (GPIO14), JP1.20
/GPIO15: J7.3, J8.3, J14.20 (GPIO15), JP1.18
/GPIO16: J14.21 (GPIO16), JP1.22, JP1.30
/GPIO17: J14.22 (GPIO17), JP1.24, JP1.32
/GPIO18: J14.24 (GPIO18), JP1.34, U2.1 (~CE)
/GPIO19: J14.25 (GPIO19), JP1.36, U2.6 (SCLK)
/GPIO20: J14.26 (GPIO20), U2.5 (SI/SIO)
/GPIO21: J14.27 (GPIO21), JP1.26
/GPIO22: J14.29 (GPIO22), JP1.16
/GPIO26: J14.31 (GPIO26_ADC0), R114.2, U6.12 (RCLK), U7.12 (RCLK), U12.3 (DATA)
/GPIO27: J14.32 (GPIO27_ADC1), R113.2, U6.11 (SRCLK), U7.11 (SRCLK), U12.1 (SCLK)
/GPIO28: J14.34 (GPIO28_ADC2), R109.1, R110.1, U6.14 (SER), U12.2 (LRCK)
/KB_CLK: J4.5, J15.13 (12), R4.2, R5.1
/KB_DATA: J4.1, J15.12 (11), R6.1, R7.2
/LOAD_IN_D: JP1.15, Q1.3 (C), R23.2
/MS_CLK: J4.6, J15.16 (15), R9.2, R11.1
/MS_CLK_3V: D4.1 (K), JP1.19, R11.2
/MS_DATA: J4.2, J15.15 (14), R8.2, R10.1
/MS_DATA_3V: D3.1 (K), JP1.17, R10.2
/Micro SD/DAT1: J5.P8 (DAT1), J6.8 (DAT1)
/Micro SD/DAT2: J5.P1 (DAT2), J6.1 (DAT2)
/PSR_SOSIO: JP1.25, JP2.2 (B)
/PWM_OUT_L: JP1.1, R112.2, R116.1
/PWM_OUT_R: JP1.3, R111.2, R115.1
/Power/D+: J3.6 (DP1), J3.8 (DP2)
/Power/D-: J3.5 (DN2), J3.7 (DN1)
/RS232/C1+: C13.2, U3.1 (C1+)
/RS232/C1-: C13.1, U3.3 (C1-)
/RS232/C2+: C14.2, U3.4 (C2+)
/RS232/C2-: C14.1, U3.5 (C2-)
/RS232/CTS_IN: J20.7, U3.7 (T2OUT)
/RS232/CTS_MAX: D8.1 (K), U3.9 (R2OUT)
/RS232/RTS_IN: J20.8, U3.8 (R2IN)
/RS232/RX_IN: J20.3, U3.14 (T1OUT)
/RS232/RX_MAX: D9.1 (K), U3.12 (R1OUT)
/RS232/TX_IN: J20.2, U3.13 (R1IN)
/RS232/V+: C12.1, U3.2 (V+)
/RS232/V-: C15.1, U3.6 (V-)
/RS232_CTS: D8.2 (A), JP1.33, R53.1
/RS232_RTS: JP1.35, U3.10 (T2IN)
/RS232_RX: D9.2 (A), JP1.31, R54.1
/RS232_TX: JP1.29, U3.11 (T1IN)
/RUN: J14.30 (RUN), S1.1
/SHND: JP1.13, R97.2, U10.12 (SHND)
/TDA_L: JP1.5, R118.2, U12.6 (A_LEFT)
/TDA_R: JP1.7, R117.1, U12.8 (A_RIGHT)
/TS_L: JP1.9, R57.1, R59.1, R60.1, R61.1, R62.1, R85.1, R87.1, R89.1
/TS_R: JP1.11, R55.1, R56.1, R58.1, R63.1, R64.1, R84.1, R86.1, R88.1
/USB Hub/DM_IN: J21.2, U9.10 (DMU)
/USB Hub/DP_IN: J21.1, U9.11 (DPU)
/USBH_VBUS: C23.1, JP1.37, U9.13 (VDD5)
/USB_D1M: J15.4 (3), R29.1, U9.7 (DM3)
/USB_D1P: J15.3 (2), R27.1, U9.8 (DP3)
/USB_D2M: J15.6 (5), R30.1, U9.5 (DM2)
/USB_D2P: J15.5 (4), R28.1, U9.6 (DP2)
/ZERO_VBUS: J15.23 (5V), JP1.27
GND: C1.2, C2.2, C3.2, C4.1, C5.2, C6.2, C7.2, C9.2, C10.2, C15.2, C16.2, C17.2, C18.2, C19.2, C20.2, C21.1, C22.1, C23.2, C24.2, C26.2, C27.2, C29.1, C30.1, C35.1, C36.2, C37.2, C38.2, C39.2, C40.2, D1.2 (A), D2.2 (A), D3.2 (A), D4.2 (A), D5.2 (A), D6.2 (A), J1.1, J2.2, J3.1 (GND), J3.12 (GND), J3.13 (SHIELD), J4.3, J5.G1 (GND_1), J5.G2 (GND_2), J5.G3 (GND_3), J5.P6 (VSS), J6.6 (VSS), J7.8, J8.8, J9.2 (G_D2), J9.5 (G_D1), J9.8 (G_D0), J9.11 (G_CLK), J9.17 (G_DDC/CEC), J9.20 (SHIELD1), J9.21 (SHIELD2), J9.22 (SHIELD3), J9.23 (SHIELD4), J12.S, J13.S, J14.3 (GND), J14.8 (GND), J14.13 (GND), J14.18 (GND), J14.23 (GND), J14.28 (GND), J14.33 (AGND), J14.38 (GND), J15.22 (GND), J16.4 (GND1), J16.8 (GND2), J16.9 (Shield), J17.0, J17.5, J17.6, J17.7, J17.8, J17.10, J18.1, J19.2, J20.5, JP1.14, LD1.1 (K), Q1.2 (E), Q2.2 (E), Q3.2 (E), R1.1, R2.1, R26.2, R52.1, R57.2, R58.2, R65.1, R91.1, R92.1, R94.2, R95.2, R102.1, R107.1, R108.1, R115.2, R116.2, R117.2, R118.1, S1.2, S2.2, U1.1 (GND), U2.4 (VSS), U3.15 (GND), U4.1 (VSS), U4.24 (~A9), U5.1 (VSS), U5.24 (~A9), U6.8 (GND), U6.13 (~OE), U7.8 (GND), U7.13 (~OE), U8.7 (GND), U9.15 (GND), U9.16 (GND), U10.2 (PGND), U10.11 (GND), U10.15 (PGND), U11.4 (V-), U12.4 (AGND)
unnamed: C8.1, J13.T, R26.1
unnamed: C8.2, R25.1
unnamed: C11.1, R40.2
unnamed: C25.2, R96.2
unnamed: C28.2, R98.2
unnamed: C31.2, R103.2
unnamed: C32.1, R104.1, U11.7
unnamed: C33.2, R105.2
unnamed: C34.1, R106.1, U11.1
unnamed: C36.1, R109.2, R111.1, R114.1
unnamed: C37.1, R110.2, R112.1, R113.1
unnamed: D7.2 (A), Q2.3 (C), R22.2, R24.1
unnamed: D7.1 (K), Q2.1 (B), R25.2
unnamed: D10.1 (K), U7.6 (QG)
unnamed: D11.1 (K), S2.1
unnamed: J3.4 (CC1), R1.2
unnamed: J3.10 (CC2), R2.2
unnamed: J7.2, R12.2
unnamed: J8.2, R13.2
unnamed: J9.12 (CLKN), R14.1
unnamed: J9.10 (CLKP), R15.1
unnamed: J9.9 (D0N), R16.1
unnamed: J9.7 (D0P), R17.1
unnamed: J9.6 (D1N), R18.1
unnamed: J9.4 (D1P), R19.1
unnamed: J9.3 (D2N), R20.1
unnamed: J9.1 (D2P), R21.1
unnamed: J14.36 (3V3), JP3.1 (A)
unnamed: J16.3 (D1+), R27.2
unnamed: J16.2 (D1-), R29.2
unnamed: J16.7 (D2+), R28.2
unnamed: J16.6 (D2-), R30.2
unnamed: J17.1, R31.2, R34.2
unnamed: J17.2, R32.2, R35.2
unnamed: J17.3, R33.2, R36.2
unnamed: J17.13, R37.1
unnamed: J17.14, R38.1
unnamed: J20.1, J20.4, J20.6
unnamed: JP2.1 (A), U2.2 (SO/SIO)
unnamed: LD1.2 (A), R3.1
unnamed: LD2.1 (K), R91.2
unnamed: LD3.1 (K), R92.2
unnamed: Q1.1 (B), R24.2
unnamed: C22.2, Q3.1 (B), R93.1, X1.1
unnamed: C21.2, Q3.3 (C), R90.1, R93.2, U8.3 (C), X1.2
unnamed: R39.2, R40.1, R41.2, R42.2
unnamed: R42.1, R43.2, R44.2
unnamed: R44.1, R45.2, R46.2
unnamed: R46.1, R47.2, R48.2
unnamed: R48.1, R49.2, R50.2
unnamed: R50.1, R51.2, R52.2
unnamed: R65.2, R66.1, R73.1
unnamed: R66.2, R67.1, R74.1
unnamed: R67.2, R68.1, R75.1
unnamed: R68.2, R69.1, R76.1
unnamed: R69.2, R70.1, R77.1
unnamed: R70.2, R71.1, R78.1
unnamed: R71.2, R72.1, R79.1
unnamed: U6.9 (QH'), U7.14 (SER)
unnamed: U8.2 (D), U8.6 (~Q)
unnamed: U9.12 (VD33), U9.14 (VD3)
unnamed: R96.1, U10.7 (INL)
unnamed: R98.1, U10.10 (INR)
unnamed: C27.1, U10.8 (VREF)
unnamed: C35.2, R101.1, R108.2, U11.3 (+), U11.5 (+)
unnamed: R105.1, R106.2, U11.2 (-)
unnamed: R103.1, R104.2, U11.6 (-)
unnamed: C38.1, U12.7 (FLT)
VBUS: C1.1, C3.1, C5.1, C9.1, C10.1, C12.2, C16.1, C17.1, C18.1, C19.1, C20.1, C24.1, C26.1, C29.2, C30.2, C39.1, C40.1, J2.3, J3.2 (VBUS), J3.11 (VBUS), J4.4, J7.6, J8.6, J9.18 (+5V), J14.40 (VBUS), J16.1 (VBUS1), J16.5 (VBUS2), J18.2, JP1.28, JP1.38, R4.1, R7.1, R8.1, R9.1, R81.1, R82.1, R83.2, R90.2, R97.1, R101.2, U1.3 (VI), U3.16 (VCC), U4.28 (BC2), U4.40 (VCC), U5.28 (BC2), U5.40 (VCC), U6.10 (~SRCLR), U6.16 (VCC), U7.10 (~SRCLR), U7.16 (VCC), U8.1 (~R), U8.4 (~S), U8.14 (VCC), U10.4 (PVDD), U10.5 (MUTE), U10.6 (VDD), U10.13 (PVDD), U11.8 (V+), U12.5 (VA)

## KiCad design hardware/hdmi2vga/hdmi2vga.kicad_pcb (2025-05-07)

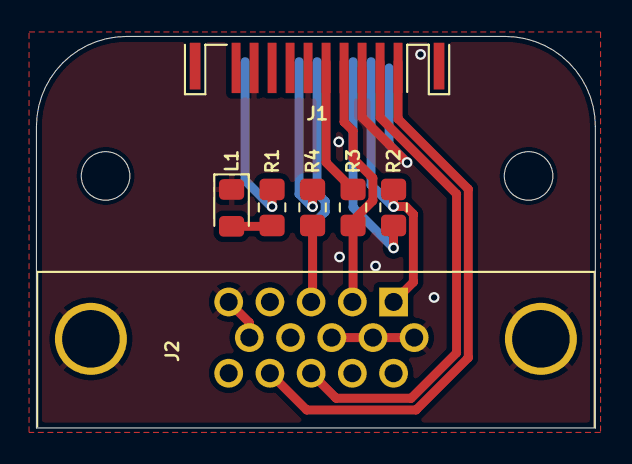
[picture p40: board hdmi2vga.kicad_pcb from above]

Board: 2 copper layers, 31.1 x 21.8 mm, 9 parts (0 on the bottom side), 11 nets.

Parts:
H1, H2: MountingHole; Mounting Hole (2.7mm)
J1: HDMI; HDMI (male)
J2: VGA; D-SUB (15 pin, female)
L1: HDMI LED; LED (0805)
R1: 1K; Resistor (0805)
R2, R3, R4: 820R; Resistor (0805)

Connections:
/CLKN_VGA_B: J1.12 (CLKN), R4.1
/CLKP_VGA_BH: J1.10 (CLKP), J2.3, R4.2
/D0N_VGA_G: J1.9 (D0N), R3.1
/D0P_VGA_GH: J1.7 (D0P), J2.2, R3.2
/D1N_VGA_R: J1.6 (D1N), R2.1
/D1P_VGA_RH: J1.4 (D1P), J2.1, R2.2
/D2N_VGA_HS: J1.3 (D2N), J2.13
/D2P_VGA_VS: J1.1 (D2P), J2.14
GND: J1.2 (G_D2), J1.5 (G_D1), J1.8 (G_D0), J1.11 (G_CLK), J1.17 (G_DDC/CEC), J2.0, J2.5, J2.6, J2.7, J2.8, J2.10, L1.1 (K)
unnamed: J1.18 (+5V), R1.1
unnamed: L1.2 (A), R1.2

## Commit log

2025-03-16 TurboFRANK HW 1.03
    [SO-8_5.3x6.2mm_P1.27mm.step, Ts-1233_1.5.stp, audio.kicad_sch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]
2025-03-16 Moved WIP to lab
    [3225 SMD Crystal Oscillator.STEP, 3v.kicad_sch, 47571-0001.stp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]
2025-03-16 Fixed tape loading bug on all PCBs
    [CMZJ2.kicad_pcb, CMZJ2.kicad_sch, HR3FQ.kicad_pcb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]
2025-03-17 TurboFRANK 1.04 WIP
    [amp.kicad_sch, audio.kicad_sch, composite.kicad_sch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]
2025-03-18 TurboFRANK HW 1.04 WIP
    [PJ320D.STEP, amp.kicad_sch, pwm.kicad_sch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]
2025-03-19 TurboFRANK HW 1.04 (release)
    [amp.kicad_sch, audio.kicad_sch, composite.kicad_sch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]
2025-03-24 RM1E WIP
    [47571-0001.stp, CUI_DEVICES_RCJ-013.step, DSUB-15-HD_Male_Horizontal_P2.29x1.98mm_EdgePinOffset3.03mm_Housed_MountingHolesOffset4.94mm.step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]
2025-03-24 MiniFRANK RM1E HW 1.00
    [47571-0001.stp, CUI_DEVICES_RCJ-013.step, DSUB-15-HD_Male_Horizontal_P2.29x1.98mm_EdgePinOffset3.03mm_Housed_MountingHolesOffset4.94mm.step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]
2025-03-26 FRANK M1 1.16 WIP
    [CMZJ2.kicad_pcb, CMZJ2.kicad_sch, audio.kicad_sch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]
2025-03-26 FRANK M1 1.16
    [CMZJ2.kicad_pcb, CMZJ2.kicad_sch, PJ320D.STEP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]
2025-04-01 Minor updates
    [3v.kicad_sch, CMZJ2.kicad_pcb, CUI_DEVICES_RCJ-013.step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]
2025-04-01 MiniFRANK RM1 2.03
    [W25Q128JVSIQ.stp, minifrank_rm1.kicad_pcb]
2025-04-04 TurboFRANK WIP
    [amp.kicad_sch, audio.kicad_sch, composite.kicad_sch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]
2025-04-04 TurboFrank HW
    [amp.kicad_sch, audio.kicad_sch, composite.kicad_sch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]
2025-04-05 TurboFRANK 1.05 HW
    [FHU-1x1.step, FHU-1x10.step, FHU-1x11.step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]
2025-04-05 TurboFRANK HW 1.05 Release
    [FHU-1x1.step, FHU-1x10.step, FHU-1x11.step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]
2025-04-07 MiniFRANK RM1 WIP
    [amp.kicad_sch, minifrank_rm1.kicad_pcb, minifrank_rm1.kicad_sch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]
2025-04-07 MiniFRANK 2.05 Release
    [amp.kicad_sch, audio.kicad_sch, gamepad.kicad_sch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]
2025-04-08 RM24 WIP
    [CUI_DEVICES_RCJ-013.step, DSUB-15-HD_Male_Horizontal_P2.29x1.98mm_EdgePinOffset3.03mm_Housed_MountingHolesOffset4.94mm.step, ESP8266-12E_ESP-12E.step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]
2025-04-09 FRANK M1 1.17
    [CMZJ2.kicad_pcb, CMZJ2.kicad_sch, audio.kicad_sch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]
2025-04-09 MiniFRANK RM24 1.01
    [amp.kicad_sch, audio.kicad_sch, gamepad.kicad_sch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]
2025-04-09 Added missing 3D models for Protea
    [47571-0001.stp, CUI_DEVICES_RCJ-013.step, DSUB-15-HD_Male_Horizontal_P2.29x1.98mm_EdgePinOffset3.03mm_Housed_MountingHolesOffset4.94mm.step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]
2025-04-15 Minor fixes
    [1x20 Male Pin Header.STEP, 1x5 Male Pin Header.STEP, 1x9 Male Pin Header.STEP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]
2025-04-16 PicoFRANK2 WIP
    [3v.kicad_sch, 47571-0001.stp, 74HC4052D,653.stp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]
2025-04-16 Experimental boards added
    [3225 SMD Crystal Oscillator.STEP, 3v.kicad_sch, 47571-0001.stp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]
2025-04-24 MiniFRANK RM1 2.07
    [audio_multiplexer.kicad_sch, minifrank_rm1.kicad_pcb, minifrank_rm1.kicad_sch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]
2025-04-24 MiniFRANK RM1e archived
    [3v.kicad_sch, 47571-0001.stp, 74HC4052D,653.stp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]
2025-05-01 TurboFRANK HW 1.07
    [amp.kicad_sch, audio.kicad_sch, composite.kicad_sch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]
2025-05-06 Nyx2 HW 1.03
    [ASMPH-0806-3R3M-T.stp, LQH2MCN100K02L.step, nyx2.kicad_pcb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]
2025-05-07 Protea is not a part of FRANK anymore
    [3v.kicad_sch, 47571-0001.stp, CUI_DEVICES_RCJ-013.step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]
2025-05-07 Revision 2.03
    [hdmi.kicad_sch, hdmi2vga.kicad_pcb, hdmi2vga.kicad_sch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]
2025-05-11 MiniFRANK RM2 WIP
    [3225 SMD Crystal Oscillator.STEP, 3v.kicad_sch, 47571-0001.stp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]
2025-05-11 MiniFRANK RM2 1.02
    [amp.kicad_sch, audio.kicad_sch, audio_multiplexer.kicad_sch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]
2025-05-11 MiniFRANK RM1 2.07: Minor Updates
    [minifrank_rm1.kicad_pcb]
2025-05-22 Улучшения разводки
    Некоторые простые компоненты - например сопротивления и конденсаторы были выровнены. Другие компоненты свое положение не меняли. Улучшена общая компоновка проводников, которая лучше использует свобод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
    [CMZJ2.kicad_pcb]
